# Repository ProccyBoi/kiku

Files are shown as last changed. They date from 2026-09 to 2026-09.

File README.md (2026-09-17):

# kiku

kiku is an open-source portable audio player built around an STM32H523 microcontroller. The project combines Bluetooth audio, local microSD playback, FM radio, a colour display, headphone and speaker outputs, battery management, and a custom mechanical enclosure in one hardware/firmware repository.

> **Project status:** this repository is a public engineering snapshot, not a production-approved hardware release. The firmware software gate passes on the checked-in source, but physical product qualification is still in progress. In particular, the Rev-A USB-C/power-path issue and the remaining hardware soak/validation items in [`Firmware/RELEASE_CHECKLIST.md`](Firmware/RELEASE_CHECKLIST.md) must be resolved before treating the design as production-ready. Files under `Production/` are therefore prototype/reference manufacturing outputs, not a production release.

## Features

- Bluetooth A2DP sink with AVRCP transport control and metadata through a Microchip BM83
- WAV and MP3 playback from a 4-bit SDMMC microSD card
- FM tuning, seek and RDS using the Silicon Labs SI4705-D60
- TLV320AIC3104 headphone/codec path and MAX98357A internal-speaker amplifier
- automatic headphone/speaker routing
- 2.0-inch 240 x 320 ST7789 display, rotary encoder and push-button controls
- BQ25895 charging/power-path control and MAX17048 battery state-of-charge monitoring
- FreeRTOS-based STM32H523 firmware with host tests, release/debug builds, watchdogs and diagnostics
- project-owned enclosure CAD, printable parts and mechanical packaging tools

## Hardware

The KiCad project in the repository root is the electrical hardware source of truth. The current board uses:

| Function | Device |
| --- | --- |
| Application MCU | STM32H523VET6 |
| Bluetooth audio | Microchip BM83, A2DP sink |
| Audio codec / headphones | TI TLV320AIC3104 |
| Speaker amplifier | Analog Devices MAX98357A |
| FM receiver | Silicon Labs SI4705-D60 |
| Charger / power path | TI BQ25895 |
| Fuel gauge | Analog Devices MAX17048 |
| Display | HS20HS072RX, ST7789, 240 x 320 |
| Storage | 4-bit SDMMC microSD |

The board is programmed and debugged through **SWD**. On this hardware revision, USB-C D+/D- are used by the BQ25895 input-detection circuitry and are **not routed to STM32 PA11/PA12**, so USB DFU/CDC is not available.

The historical `Walkman - Blobject.*` KiCad/manufacturing filenames are retained in this snapshot to avoid breaking project references and release tooling; the public project name is **kiku**.

## Firmware

Firmware is under [`Firmware/`](Firmware/README.md). It implements Bluetooth, local-file and FM source handling; audio routing; display and controls; battery/charger monitoring; persistent settings; watchdog/fault handling; and bring-up diagnostics.

Initialise the pinned submodules and run the host/build checks from the repository root:

```text
git submodule update --init --recursive
python Firmware/tools/test_host.py
python Firmware/tools/build.py --clean
```

For a software release candidate, run:

```text
python Firmware/tools/release_check.py --require-clean
```

The firmware build outputs `kiku.elf`, `kiku.bin`, `kiku.hex` and `kiku.map` under `Firmware/build/`. See [`Firmware/README.md`](Firmware/README.md) for the BM83 configuration contract, programming steps, controls and bring-up details.

## Mechanical design

[`Mechanical/`](Mechanical/README.md) contains the enclosure source, public STEP/STL outputs, review material and packaging scripts.

The project intentionally does **not** redistribute component 3D models whose upstream redistribution terms are unclear, nor generated populated/reference assemblies that embed those models. Public mechanical packages use project-owned geometry and recorded QA metadata. Exact component-level fit checking remains a local workflow after obtaining the required manufacturer/KiCad models under their original terms.

See [`Mechanical/REFERENCE_GEOMETRY.md`](Mechanical/REFERENCE_GEOMETRY.md) for the complete provenance and reproducibility workflow.

## Repository layout

```text
Firmware/                       STM32 firmware, tests and build/release tooling
Mechanical/                     enclosure CAD, exports, QA and packaging tools
Production/                     prototype/reference PCB manufacturing outputs
3dmodels/README.md              policy for locally obtained component models
Walkman - Blobject.kicad_*      KiCad project sources
Print.pdf                       generated PCB print output
Print Schematic.pdf             generated schematic print output
.github/workflows/firmware.yml  firmware CI
```

## Public-source scope

This repository publishes project-authored hardware, firmware and mechanical sources while deliberately excluding material that should remain with its upstream publisher. Excluded material includes third-party BM83 firmware/configuration tools and command-set documents, generated radio images, cached supplier pages, vendor datasheet copies, provenance-unclear component 3D models, and fit-check assemblies that serialise those models.

Third-party source code that is present in the tree or pulled as a submodule remains under its own upstream copyright and licence notices. The project licence does not replace those terms.

## Validation

The public snapshot is checked with:

- native firmware regression tests plus clean release/debug ARM builds;
- `Firmware/tools/release_check.py --require-clean`;
- stripped-checkout P0/P1 mechanical package builds that exclude third-party reference geometry;
- Git history, integrity, privacy and credential scans before publication.

Passing these source/software checks does not replace the physical hardware, RF, charging, mechanical, regulatory or long-duration soak tests listed in [`Firmware/RELEASE_CHECKLIST.md`](Firmware/RELEASE_CHECKLIST.md).

## Licence

kiku is a mixed-licence project:

- project-authored hardware, electronics and mechanical design material is licensed under **CERN-OHL-P-2.0**;
- project-authored firmware, tools, scripts and CI code is licensed under the **MIT License**;
- files or portions carrying their own third-party copyright/licence notices remain under those upstream terms.

The exact scope map and full licence texts are in [`LICENSE`](LICENSE) and [`LICENSES/`](LICENSES/).

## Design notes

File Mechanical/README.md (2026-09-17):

# Kiku mechanical enclosure

This folder contains the mechanical source and prototype exports for the Kiku portable audio player. The enclosure is built around the **current KiCad PCB**, not a generic board envelope.

## V8 direction

The first CAD iteration combines the earlier **Pebble clamshell** and **Lens Island** directions:

- 69 x 115 mm rounded handheld body with an 11 mm plan-view corner radius.
- 1.8 mm nominal walls for an SLS/MJF or careful FDM first prototype.
- Flush separate screen lens over the HS20HS072RX LCD.
- **Two paired pebble tactile caps** with hidden split press-fit sockets on SW3/SW4. They are rotated slightly toward each other and sit in shallow organic recesses rather than looking like generic square caps. SW1/QON remains internal.
- **Soft encoder puck** with a hidden split-collet press fit on the PEC11L 6 mm knurled shaft. A recessed M7x0.75 bushing-nut pocket is hidden underneath so the encoder can mechanically support the shell rather than loading only its solder joints.
- Real bottom USB-C and 3.5 mm jack positions from KiCad.
- Softer top microSD access: a narrower card tunnel plus a broad thumb scallop instead of a rectangular cut-out.
- Four M2 PCB standoffs at the actual board holes plus lower-edge support rails.
- Rear-to-front perimeter locating tongue with first-print slip-fit clearance.
- **Two hidden M2 case screws beneath the removable screen lens**, reusing the PCB's existing upper 2.2 mm mounting holes. Rear posts include pockets for small M2 brass inserts, so the finished exterior has no visible enclosure screws.
- **Uniform smooth rear shell** deep enough for the supplied 10 x 34 x 50 mm LiPo. The previous local battery hump has been removed.
- **No internal speaker**. LS1 remains available electrically and a 4.4 mm right-side cable egress is provided for an externally mounted speaker lead.
- **Recessed multimeter-style kickstand** on the rear. The 42 x 56 mm open-frame stand sits nearly flush when closed and uses a 1.9 mm hinge bore intended for ~1.75 mm filament or a similar smooth pin.
- **Left-side SMA bulkhead** for the external FM antenna.
- Reserved 100 mm RF1.13 U.FL-to-SMA cable route from PCB J3, down the right side and then across below the battery, deliberately leaving the BM83 lower-right RF keepout before crossing the case.
- Hinged telescopic antenna stows upward along the left side instead of lying across the rear face, with two open crescent nesting saddles to make the folded whip look intentionally parked.
- Explicit lower-right BM83/RF keepout: no battery foil, speaker magnet, metal boss or antenna-coax bundle should be added there.

V8 deliberately prioritises appearance over absolute minimum thickness. The body remains a uniform **28.7 mm nominal thickness**, absorbing the 10 mm battery without a rear hump and keeping the front speaker-free. Fasteners are hidden beneath the screen lens, the microSD opening is softened into the top edge, and the folded FM whip gains intentional nesting features rather than hanging loose from the SMA hinge.

## Source of truth

`reference/board_datums.json` is generated from `Walkman - Blobject.kicad_pcb` by `scripts/extract_board.py`. Its mechanical coordinate system is:

- X = PCB X - 72.11 mm
- Y = 157.90 mm - PCB Y
- Z = 0 at PCB rear, +1.6 mm at PCB front

Do not hand-edit the KiCad-derived datums. Re-run the extractor after board changes, then rebuild and review the enclosure.

## Build

Project-owned enclosure/part source and exports are redistributable. The strict
hardware fit-check additionally requires the component 3D models referenced by
the KiCad board; those inputs are intentionally not bundled. See
`REFERENCE_GEOMETRY.md` before rerunning a full hardware-reference validation.

From the repository root, after preparing those local references when a full
fit-check is required:

```powershell
python Mechanical/scripts/build_housing.py
```

CadQuery 2.8 or newer is required.

## Exported parts

`exports/` contains project-owned STEP and STL for:

- front shell
- rear shell
- rear kickstand
- screen lens
- left/right button caps
- encoder knob
- housing-only assembly STEP
- individual printable/manufactured parts
- packaging/keepout STEP

The populated PCB fit-check STEP is a local generated artefact because it embeds
third-party component-model geometry. It is intentionally not redistributed.
The public tree retains `reference/pcb_bare.step`, board datums, component
reference metadata, project-owned housing geometry and recorded QA results.

`review/` also contains validation data and front/rear/exploded PNGs generated by:

```powershell
python Mechanical/scripts/render_review.py
```

Third-party datasheet copies, supplier-page captures and component-library 3D
models used during development are intentionally not redistributed by the public
source tree unless their licence is explicitly recorded. The reports retain the
source links and measured requirements needed to reproduce the design review;
project-derived PCB/enclosure geometry remains checked in.

P0/P1 frozen `REF_*.brep` files and populated fit-check assemblies are likewise
local-only. They can be regenerated after obtaining the exact model inputs under
their original terms; the public packaging scripts never copy them into a
redistributable package.

## Parameters that are intentionally not production-frozen

- LiPo pack: V8 uses the supplied **10 x 34 x 50 mm** envelope. The stated capacity is 200 mAh; dimensions are treated as the mechanical source of truth. Final cable exit, protection-PCB position and swelling allowance still need physical verification.
- Speaker: V8 intentionally has **no internal speaker cavity, grille or speaker bulge**. The LS1 PicoBlade output remains on the PCB and exits through the right-side cable passage for an externally mounted speaker.
- Kickstand: V8 uses a recessed open-frame stand with a nominal **62 degree open reference angle**. The first prototype uses hinge friction rather than a moulded detent; tune or drill the 1.9 mm bore for the chosen print process/pin if needed.
- LCD: body and active-area dimensions follow the current HS20HS072RX drawing, but final adhesive/foam stack and FPC bend need a physical fit check.
- FM: the ordered pigtail is an RF1.13 U.FL/IPX-to-SMA bulkhead lead; the 100 mm option is reserved. The ordered telescopic antenna listing shows **105 mm collapsed, 310 mm extended and 9 mm diameter** with a hinge. V8 mounts the SMA on the left side at Y=18 mm, reserves an 88.3 mm internal route plus service slack, and adds open nesting saddles at Y=48 and 84 mm.
- Controls: SW3/SW4 use a measured/modelled 7.2 mm square actuator. V8 caps use a nominal 7.05 mm four-way split socket with a larger lead-in, giving a deliberately small compliant press fit instead of a loose post. The encoder uses a 5.75 mm split-collet bore on the 6.0 mm 18-tooth knurled shaft. PA12 is preferred for these compliant details; FDM users should tune the press fits from the first test print if required.
- Fastening: use two low-profile/button-head M2 screws with **head height <= 1.3 mm** through the upper PCB mounting holes, into the rear post insert pockets. Tighten these before fitting the screen lens; the lens then conceals both screw heads.
- Positive snap retention / cosmetic parting-line refinement / heat-set insert details are deliberately deferred until V1 dimensional fit is verified; V1 includes a locating tongue but is intended to be taped/clamped for the first dimensional fit if required.

## First prototype review

Before treating this as production CAD, verify:

1. PCB drops onto all four posts without stress and the lower cradle does not contact solder joints.
2. USB-C and headphone plugs fully seat through the case openings.
3. microSD can be inserted and removed comfortably through the top thumb scallop with the LCD installed.
4. Both pebble caps press securely onto SW3/SW4, remain removable with deliberate pulling force, and do not preload the switches.
5. Button caps move through the tactile travel without rubbing the front-shell recesses.
6. Encoder split collet grips the 6.0 mm knurled shaft securely; optional M7x0.75 nut/washer clears beneath it and push-to-select still has full travel.
7. Battery does not touch the PCB, mounting screws, coax route or rear-wall features.
8. External speaker lead passes freely through the 4.4 mm right-side egress.
9. Kickstand closes into its recess, rotates freely, and provides useful friction with the selected hinge pin.
10. Hidden M2 screws clamp the shell/PCB stack correctly, their heads stay below the lens underside, and the lens can still be removed for service.
11. SMA bulkhead/nut fits the 6.8 mm left-side hole, U.FL/coax reaches without entering the BM83 keepout, and the hinged antenna rests cleanly in both side saddles without fouling the case.

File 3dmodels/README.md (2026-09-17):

# Component 3D models

The public source tree intentionally does not redistribute the local component
3D-model bundle. Several models originate from manufacturer/library/EasyEDA
sources and the project does not have a single documented redistribution licence
covering the complete bundle.

The KiCad schematic and PCB remain the electrical source of truth and do not
require these optional models for fabrication or firmware builds. For local 3D
review, obtain the applicable models from the original manufacturer, KiCad
library or component-library source under its own licence and place them in this
directory using the filenames referenced by the board. Local model files are
ignored by Git. `Mechanical/REFERENCE_GEOMETRY.md` documents the exact local
reference workflow and the source audit command.

Project-generated enclosure, bare-PCB and manufacturing geometry remains under
`Mechanical/` and `Production/` where it is part of the kiku source tree. A
populated PCB STEP, frozen transformed component BREPs and fit-check assemblies
that embed those third-party models are intentionally local-only outputs.

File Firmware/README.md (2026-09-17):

# kiku firmware

Production-oriented firmware for the STM32H523VET6 board in the repository root. The KiCad schematic/PCB is the hardware source of truth; the firmware pin map is deliberately kept in `Core/Inc/board.h` and `Core/Src/board.c` rather than a generic development-board definition.

## Implemented product functions

- BM83 Bluetooth A2DP receive path over I2S2, Host MCU UART framing/ACK, MFB wake timing, AVRCP play/pause/next/previous and AVRCP 1.3 title/artist/album metadata requests.
- microSD library scan over 4-bit SDMMC1 with UTF-8 long filenames, hot-insert remount/rescan, PCM WAV playback and MP3 playback through minimp3. A missing card is non-fatal.
- SI4705 FM power-up, tune, seek, signal-quality polling and RDS Program Service/RadioText decoding. FM analogue L/R is routed into the TLV320AIC3104 ADC and looped through the I2S1 DAC/speaker path so both headphones and the internal speaker receive the selected station.
- TLV320AIC3104 I2S/headphone routing plus MAX98357A speaker control with selectable AUTO, headphones, speaker and both-output modes. AUTO uses the speaker when the jack is empty and headphones when a plug is inserted.
- BQ25895 charger status and MAX17048 battery state-of-charge monitoring. Rev A is forced to a 5-V-only, 500-mA input profile at the very start of platform initialisation: automatic D+/D- detection, HVDCP and MaxCharge negotiation are disabled before slow peripheral work. Charge-current programming remains disabled by default because the final cell/enclosure/thermistor limits cannot be derived from the PCB.
- ST7789 320x240 status/now-playing UI, PWM backlight, rotary encoder and three push controls.
- CRC-protected persistent settings (`KIKU.CFG` on microSD, with read-only migration from the older development filename), watchdog, non-destructive peripheral self-test API and recoverable optional-peripheral failures.
- FreeRTOS on Cortex-M33, HAL timebase isolated on TIM6, DMA-capable peripheral setup and exact STM32H523 startup/linker configuration.

## Controls

| Control | Local audio | FM | Bluetooth |
| --- | --- | --- | --- |
| Encoder | Volume | Volume by default; fine tune when toggled | Volume |
| Encoder press | Open SD/library menu | Toggle FM knob between volume/tune | Return to sources |
| Encoder long press | Return to sources | Return to sources | Return to sources |
| Button 1 | Play/pause | Previous preset | Play/pause |
| Button 1 long press | Switch to local | Seek down | Pair if disconnected; otherwise local |
| Button 2 | Next/random track | Next preset | Next track |
| Button 2 long press | Switch to FM | Seek up | Switch to FM |

Shuffle is owned by the SD/library menu rather than global Settings. It changes
local next-track selection only and is persisted with the other user settings.

When Bluetooth is selected, firmware automatically reconnects the last paired
A2DP device with bounded backoff. Normal BM83 UART traffic does not pulse MFB;
BM83 does not expose the `UART_RX_IND` function used by earlier BM62/BM64 parts.
If no device reconnects, the Bluetooth screen shows `HOLD B1 TO PAIR`; holding
Button 1 enters BM83 pairing mode without clearing existing pairing records.

## Required BM83 configuration

The PCB gives the BM83 its own digital-audio clock path but does not route BM83 MCLK to the STM32. This firmware therefore expects the BM83 configuration image to use:

- Host MCU mode enabled;
- UART at 115200 baud;
- A2DP sink and AVRCP enabled;
- I2S audio output at 48 kHz, 24-bit stereo;
- BM83 acting as the I2S BCLK/LRCLK host (STM32 I2S2 is configured as slave receive).

The connected development BM83 has now been measured as MSPK2 firmware v1.2.
That image is suitable for bench compatibility testing but is **not** the kiku
production radio baseline: Microchip's MSPK2 v1.3 release notes explicitly fix
the defect where firmware stops responding to UART `0x4A` after many requests.
Use an SPP Host-Mode MSPK2 v1.3-or-newer compatible image for a golden unit,
then archive its exact firmware/configuration hashes with manufacturing records.
Vendor tools, documentation and generated BM83 images are intentionally not
redistributed by this public repository; see [`BM83_tools/README.md`](BM83_tools/README.md).

If OTA DFU is not a deliberate product feature, disable it in the BM83
configuration. If it is shipped, replace all example/default credentials with a
production secret provisioned outside source control.

## Build and test

Dependencies are checked in or pinned as Git submodules. On Windows the build script automatically finds the GNU Arm toolchain installed by PlatformIO; elsewhere `arm-none-eabi-gcc`, `objcopy` and `size` can be on `PATH` or supplied through `ARM_GCC_PREFIX`.

```text
git submodule update --init --recursive
python Firmware/tools/test_host.py
python Firmware/tools/build.py --clean
```

Outputs are written to `Firmware/build/`:

- `kiku.elf`
- `kiku.bin`
- `kiku.hex`
- `kiku.map`

The same host tests plus clean release and debug cross-builds run in GitHub Actions. The workflow rebuilds release mode last so its uploaded artifacts are the production binaries.

For a release candidate, run `python Firmware/tools/release_check.py --require-clean`.
The build also emits `kiku-build-manifest.json` containing SHA-256 hashes, the
compiler identity and Git revision. The complete software/hardware sign-off is
in [`RELEASE_CHECKLIST.md`](RELEASE_CHECKLIST.md); a passing build alone does
not waive unresolved hardware validation.

## Programming

This board is programmed through the 10-pin ARM SWD connector. The USB-C D+/D- lines terminate at the BQ25895 charging circuitry; STM32 PA11/PA12 are not connected on this hardware revision, so USB DFU/CDC/MSC is not available.

With an ST-Link and STM32CubeProgrammer, a typical command after building is:

```text
STM32_Programmer_CLI -c port=SWD -w Firmware/build/kiku.hex -v -rst
```

## Audio architecture

The MCU/codec audio domain is fixed at 48 kHz. Local files from 8-96 kHz are converted to 48 kHz by a deterministic nearest-neighbour resampler before I2S output. Bluetooth PCM arrives from BM83 on I2S2. SI4705 FM analogue audio enters TLV320AIC3104 LINE2; the codec ADC return is forwarded through I2S1 to the codec DAC and MAX98357A path. AUTO output disables the speaker amplifier whenever headphones are inserted; explicit Speaker and Both modes override that automatic policy. Software volume scaling is applied before I2S transmission.

The simple resampler is intentional for first hardware bring-up and correctness. A band-limited asynchronous resampler is the appropriate later upgrade if listening tests show the BM83 and codec clock domains need drift compensation or higher-quality sample-rate conversion.

## First hardware bring-up checks

The repository is fully build/test checked without attached hardware. These physical facts still require measurement on the assembled product and are kept isolated so they do not contaminate the protocol/board implementation:

1. Program and record a golden BM83 using a compatible MSPK2 v1.3-or-newer SPP
   Host-Mode image, confirm the interface requirements above, and verify
   long-duration clock-domain and metadata behaviour. The STM32 host is hardened
   against the v1.2 repeated-`0x4A` defect, but that does not make v1.2 an
   acceptable production radio baseline.
2. Confirm `HP_DET` polarity with the actual SJ1-3525N jack; change the single active-level argument in `Platform/Src/platform.c` if required.
3. Confirm ST7789 rotation, RGB/BGR order and inversion for the exact HS20HS072RX panel; adjust the startup sequence/offset constants only if the physical panel requires it.
4. Set BQ25895 charge current/input-current/thermal policy only after the exact LiPo cell rating, NTC network and enclosure thermal performance are known. `APP_BENCH_CHARGE_POLICY_ENABLE` remains `0` by default.
5. Rev A uses F1 = C883127 (6-V, 750-mA PTC) and a 5-V-class TVS on VBUS. The BQ25895 reset defaults permit D+/D- high-voltage-adapter negotiation, so firmware explicitly disables AUTO_DPDM/HVDCP/MaxCharge and fixes IINLIM at 500 mA before SD/Bluetooth/display initialisation. This greatly reduces risk when the MCU is running, but a future PCB revision should make the 5-V-only requirement true in hardware as well rather than relying solely on post-reset I2C configuration.

## Source layout

```text
Firmware/
  Core/        STM32H523 clocks, pins, HAL MSP/IRQs, FreeRTOS config
  Drivers/     BM83, BQ25895, MAX17048, SI4705, ST7789, TLV320AIC3104, audio I/O
  Audio/       minimp3 adapter
  Storage/     FatFs/SDMMC storage and settings adapters
  App/         product state, playback, input, radio, power, settings, self-test
  Platform/    HAL-to-driver integration and audio routing
  UI/          display renderer
  tests/       native protocol/state unit tests
  tools/       reproducible build/test scripts
```

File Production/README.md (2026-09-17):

# Production outputs

This directory contains Gerber and drill outputs generated from the current kiku PCB design. They are retained as **prototype/reference manufacturing outputs** for reproducibility and review.

They are **not a production-approved fabrication release**. The current Rev-A hardware still has unresolved power/USB-C and physical qualification items documented in [`../Firmware/RELEASE_CHECKLIST.md`](../Firmware/RELEASE_CHECKLIST.md). Resolve and sign off those blockers on the intended PCB/BOM revision before ordering production hardware from these files.

The historical `Walkman - Blobject` filenames are retained to match the KiCad project and existing generated-output workflow.

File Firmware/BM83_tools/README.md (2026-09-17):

# BM83 production package

This directory intentionally does **not** redistribute Microchip BM83/IS2083
firmware, configuration tools, command-set documents or generated radio images.
Obtain the applicable BM83 software package and documentation directly from
Microchip, then archive the exact production inputs and hashes with the build
and manufacturing records rather than in the public source repository.

## kiku radio requirements

The production BM83 configuration must provide:

- MSPK2 SPP firmware v1.3 or newer compatible firmware. The connected v1.2
  development module reproduced Microchip's documented defect where repeated
  UART `0x4A` AVRCP vendor-dependent requests eventually stop receiving a
  response; the BM83 MSPK2 v1.3 release notes list this defect as fixed.
- Host MCU mode at 115200 baud.
- A2DP sink and AVRCP enabled.
- 48 kHz, 24-bit stereo I2S output with the BM83 providing BCLK/LRCLK to the
  STM32 I2S2 slave receiver.
- A production-specific Bluetooth device name and profile configuration.
- OTA DFU disabled when it is not a product requirement. If OTA DFU is shipped,
  provision a non-default production secret outside Git and include it in the
  manufacturing security process; never ship the Config Tool example/default
  key.

The STM32 firmware deliberately keeps the field-proven `0x4A` metadata path and
also serialises title, artist and album into separate physical requests. The
three fields are staged and committed atomically. An accepted request whose
`0x5D` response is missing remains owned instead of being blindly retried, so a
faulty/older BM83 cannot be driven into a UART resource-exhaustion loop.

## Golden-unit record

For every production release, record at minimum:

- BM83 8051 firmware variant and version;
- DSP firmware version;
- UART command-set / Host MCU version reported by the module;
- configuration image SHA-256;
- radio firmware image SHA-256;
- production device-name/profile configuration;
- whether OTA DFU is disabled or the identifier of the external secret record;
- a sustained metadata-soak result on the exact programmed radio image.

Do not treat files left in this directory on a development workstation as
release artefacts unless they match the signed golden-unit record.

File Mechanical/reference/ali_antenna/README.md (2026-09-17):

# FM antenna mechanical reference

Source products supplied by the project owner:

- Telescopic antenna: `https://www.aliexpress.com/item/1005007806214529.html`
- U.FL/IPX to SMA RF1.13 pigtail: `https://www.aliexpress.com/item/1005009812335103.html`

## Telescopic antenna

The listing title identifies a hinged SMA rod/telescopic antenna intended for 40 MHz to 6 GHz. Supplier dimensions recorded during the mechanical review are:

- collapsed overall length: **105 mm**
- extended overall length: **310 mm**
- maximum body/base diameter shown: **9 mm**
- 90-degree hinge at the connector end

The listing artwork is internally inconsistent about the connector naming (title says SMA while one image labels an F-type connector), so V2 does **not** assume antenna gender in the printed geometry. It provides clearance around a conventional 6.35 mm SMA bulkhead thread and leaves the removable antenna outside the print.

Cached supplier HTML and product images are deliberately excluded from the
public source tree. Use the source-product links above for the current listing;
local cached copies, when present on an engineering workstation, are ignored by
Git.

## Pigtail

The second listing is an RF1.13 coax pigtail family with U.FL/IPX at the PCB end and SMA/RP-SMA bulkhead variants. The exact ordered lead is treated mechanically as:

- nominal cable length: **100 mm**
- cable type: **RF1.13**
- PCB end: U.FL/IPX for Kiku J3
- enclosure end: SMA-style bulkhead

V2 uses a **6.8 mm bulkhead hole** and a **12 mm-diameter local reinforcement boss**. The larger boss is deliberate: if the delivered telescopic antenna/pigtail combination turns out to need a larger bulkhead despite the listing's SMA wording, the prototype hole can be cautiously opened up without reprinting the shell. The internal reserved cable centreline is approximately **88.3 mm**, allowing connector transitions and a small amount of service slack without coiling the cable tightly.

## Housing routing decision

J3 is at mechanical XY `(57.395, 66.55)` mm, very close to the right PCB edge. The cable first goes down the right side, then crosses towards the left only below the battery. The diagonal crossing leaves the lower-right BM83 RF keepout before it moves left. The bulkhead is at the left side around Y=18 mm. This also lets the hinged telescopic rod fold upward along the left side, keeping the 9 mm antenna body off the rear face and preserving the thinnest practical body profile.

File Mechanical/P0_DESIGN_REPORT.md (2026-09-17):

# Kiku / Mame P0 mechanical design

**Engineering development release. Not approved for production tooling.**

This version is generated by `scripts/housing.py` and `parameters.json`. Its outputs are isolated in `exports/P0/`. Other `kiku_*_v1` files in the parent export folder belong to a separate design iteration and are not interchangeable with these parts.

## Hardware basis and coordinate system

The current `Walkman - Blobject.kicad_pcb` is the dimensional authority. `reference/board_datums.json` records its SHA-256, every footprint position, mounting pad/drill, model transform, and board outline. The PCB file is not modified. The exact board outline, including the jack notch and asymmetric bottom-left corner, is retained in the reference STEP.

Mechanical X = KiCad X - 72.11; mechanical Y = 157.90 - KiCad Y; Z = 0 at the nominal board back, positive toward the controls. The nominal board is 60 x 105 x 1.6 mm. The KiCad bare-body STEP omits some conductor thickness; compare its reported Z extent with the nominal 1.6 mm stack before using imported surfaces as mounting datums.

| Interface | Mechanical centre X, Y (mm) | Evidence |
|---|---:|---|
| Left key SW3 | 16.000, 55.000 | KiCad footprint and supplied STEP |
| Right key SW4 | 44.000, 55.000 | KiCad footprint and supplied STEP |
| Encoder SW2 | 30.000, 40.000 | KiCad footprint; PEC11L drawing for Z |
| QON power/wake SW1 | 24.950, 20.910 | KiCad footprint and /QON net |
| USB-C J1 | 20.090, mating face Y = -0.100 | STEP mating face, axis Z = 3.250 |
| Headphone J6 | 7.570, axis parallel to Y | STEP bore, axis Z = 4.100 |
| microSD J2 | 36.965, 96.350 footprint datum | Hirose STEP; opening follows mouth |
| PCB H5/H6 | 6.000 / 54.000, 99.000 | Actual 2.2 mm drilled mounting pads |
| PCB H7/H8 | 6.000 / 54.000, 37.000 | Actual 2.2 mm drilled mounting pads |

The component inventory differentiates supplied STEP solids, envelopes extracted from VRML vertices, and the missing D3 model. VRML envelopes are conservative bounding boxes, not replacement manufacturer CAD. The encoder's attached PEC11R-labelled model reaches only about Z = 21.1 mm. Its specified PEC11L-4120F-S0020 drawing instead puts the nominal shaft tip at Z = 26.1 mm. P0 uses the specified part's dimensions and retains the discrepancy as an incoming inspection item.

## Three concepts and selection

See `concepts/three_concepts.png`, individual front/rear/profile/perspective images, and the three concept STEP files. These are exterior studies sharing the board, display, and control datums; they do not represent three independently finished mechanisms.

| Concept | Assembly approach | Advantages | Disadvantages |
|---|---|---|---|
| **Mame: soft pebble** | Two shells, internal lens carrier, rear screws | Balanced width around a fixed rectangular PCB; broad rear grip; gentle lower-left swell gives identity with screen off; suitable room for isolated cell and speaker | Fuller than the board; long encoder creates local depth; organic surface requires careful finishing |
| **Nagare: offset swell** | Same two-shell stack, larger asymmetric right-hand grip | Most expressive silhouette; thumb-side volume is comfortable for a right-handed grip | Extra width with no hardware benefit; less neutral in the left hand; greater pocket bulk |
| **Mini: restrained capsule** | Two shells with smaller perimeter allowance | Smallest outline; most familiar MiniDisc-era proportions; least plastic | Less room around side bosses and lead dress; flatter identity; tight margins make tolerances harder |

Engineering judgement scores, 1 = weak and 5 = strong; equal weighting:

| Concept | Identity | Ergonomics | Manufacture | Assembly | Robustness | Fixed hardware | Total / 30 |
|---|---:|---:|---:|---:|---:|---:|---:|
| Mame | 4 | 4 | 4 | 4 | 4 | 5 | **25** |
| Nagare | 5 | 3 | 3 | 4 | 4 | 4 | 23 |
| Mini | 3 | 4 | 4 | 3 | 3 | 4 | 21 |

Mame is selected. Scores describe design judgement, not user testing. The front is warm opaque ivory, rear satin muted green, primary key orange, other controls tonal green/ivory, and the window smoked with an opaque reverse mask. The lower front has room for a small printed Kiku wordmark; the rear upper flat has a 26 x 12 mm reserved product-information area. No false vents or decorative grooves are used.

## Stack and construction

**Approximate overall envelope: 77.1 mm wide x 120.9 mm tall x 46.8 mm deep including the knob**, from exported mesh extrema at 0.08 mm tessellation tolerance. The main shell extends from Z = -18.0 to +15.2 mm: **33.2 mm nominal body depth**. Raised keys and encoder add local depth; the knob top is Z = 28.8, so the total nominal front-to-back envelope is **46.8 mm**. This is a material ergonomics limitation of the specified 20 mm encoder shaft and the 10 mm thick battery. The interface review supplies the exported mesh extrema for approximate manufacturing envelope dimensions; the BREP inventory also records bounding boxes, which can overbound curved spline surfaces. Do not substitute a shorter shaft or thinner battery without an explicit hardware decision.

Housing skins use 1.8 mm nominal walls. Plan offsets follow sampled inward curve normals; the front/rear edge rolls approximate 3.5/4.0 mm quarter-rounds with 15-degree CAD segments. This is an explicit prototype construction, not a Class-A mould surface. Surface continuity, local wall mapping and minimum neck sections must be rebuilt/verified for tooling. Internal bridge ribs are 1.4 mm wide and locally 1.0 mm deep. Boss roots require physical torque/drop testing.

### Display and lens

The user permits a floating display above the PCB. Its body is 51.8 x 36.2 x 2.05 mm, with a 40.8 x 30.6 mm active area, from the [HS manufacturer drawing](https://atta.szlcsc.com/upload/public/pdf/source/20251016/BAE15D01F6ECB51EA8350D6C5C8F6372.pdf), sheet 10. The KiCad placement rectangle is 0.01 mm shorter in Y; P0 preserves its centre and uses the drawing's actual body size.

P0 orients the tail toward the PCB's right-side FPC connector. The active area is offset 2.66 mm left of the module centre in this orientation; the aperture follows it rather than centring it blindly in the body. The 41.6 x 31.4 mm aperture provides 0.4 mm nominal overscan per edge. The 54 x 37.8 x 1.0 mm lens is recessed 0.2 mm, with 0.3 mm perimeter clearance and a 0.2 mm adhesive seat. Mask the lens reverse face around the optical aperture. The LCD top is at Z = 12.50, with 0.40 mm nominal clearance to the bezel underside. The removable carrier supports the backlight frame through a thin compliant strip; it does not clamp the active glass.

The FPC route is a reserved folding space, not a proven cable model. Confirm the supplied tail orientation, contact side, usable length, bend radius and latch access with the actual panel before fastening the carrier. Do not sharply crease the FPC.

### Controls

Both large caps have captured flanges and a 0.35 mm nominal radial guide allowance at the exposed cap. A small underside contact feature meets the switch actuator. The actual switch operating stroke, force, and tolerance were not supplied. The housing is checked at 0, 0.5 and 1.0 mm downward cap displacement; this tests housing space, not the switch itself. Verify take-up, overtravel stop and return before powered use. Add a compliant return/anti-rattle element only after measuring the force budget.

SW1/QON remains an internal service control in this iteration; no external plunger is supplied. Confirm the intended user power/wake behaviour in firmware before accepting this interface. The encoder uses a 21 mm outside diameter knob, a 6.24 mm D-shaped nominal socket, an integrated housing guide around its skirt, and a radial M2 grub screw in a metal insert. The [Bourns PEC11L drawing](https://www.bourns.com/docs/product-datasheets/pec11l.pdf) specifies 0.5 mm nominal switch travel with +0.4/-0.3 mm tolerance; P0 reserves 1.2 mm between the knob shoulder and raised island before push. The skirt counterbore extends above the full-round shaft section; the D socket starts where the flat is available. Housing clearance is checked at 0, 0.45 and 0.9 mm downward knob displacement. Check the installed shaft length and knob axial setting over the whole 0.2-0.9 mm switch stroke.

### Battery

The user-specified cell envelope is **34 x 50 x 10 mm**, reported capacity 200 mAh. Capacity is not inferred from its physical size. Its nominal location is X = 13..47, Y = 45..95, Z = -15.2..-5.2. Foam supports the pouch; side rails provide 0.5 mm nominal lateral clearance. A removable insulating guard at Z = -3.8 leaves **1.4 mm nominal space above the pouch**, with no intentional compression from shell screws. Supplier dimensional tolerance, protection board, lead exit, and swelling requirements remain unverified. That 1.4 mm is a packaging reserve, not a claim that a damaged/swollen cell is safe to keep using.

The guard and its fasteners remain outside the nominal cell footprint. Radius/finish every pouch-facing edge. Use a pull ribbon under the battery and disconnect it before service; do not permanently bond the cell into the case. Confirm the connector's cable bend and unplugging space. A printed guard is a prototype; a smooth insulating sheet is preferable once its shape is validated.

### Speaker

Selected part: **XHXDZ 20MM-8ohm2W-JFHM, LCSC C50387209**. Its [manufacturer drawing hosted by LCSC](https://datasheet.lcsc.com/datasheet/pdf/8e0aa0a2b86c456182d861902de24ed3.pdf?productCode=C50387209) gives 20 +/- 0.2 mm diameter and 5.1 +/- 0.3 mm total depth. The alternative [C50387215](https://www.lcsc.com/product-detail/C50387215.html) is 30 mm; it is not interchangeable with this retainer.

The selected driver fires toward seven rounded rear slots. A soft rim gasket spaces the diaphragm from the grille. A separate screwed cover and compliant rear perimeter support retain the driver. The pocket is 21.0 mm diameter, giving 0.5 mm nominal radial clearance and 0.4 mm with the maximum listed diameter. A small rear cavity and a sealed wire notch avoid a direct uncontrolled front-to-back air path. The pull-tab outline is not fully dimensioned by the manufacturer; its relief is provisional. Seal the relief with compliant material, then check cone travel, rattles and acoustic leakage. The cavity has not been acoustically tuned or measured; no SPL/bass claim is made.

### Ports and antennas

The USB-C passage is a 13 x 7 mm overmould gauge following the actual mating axis; the headphone passage accepts an 11 mm cylindrical overmould on the real jack axis. These are explicit test gauges, not a guarantee for every cable. Entrance edges require a small deburr/chamfer after printing. Check full seating with a straight plug, a bulky plug, and multiple USB-C cables. The opening supports a contacting cable overmould laterally, but connector solder joints still carry loads until contact; no separate connector strain-relief rating is claimed.

The microSD tunnel and enlarged top finger relief extend back toward the socket so a thumbnail can reach the card. Verify the actual push-push latch, card lock/eject positions and fingertip access with the lens/carrier installed. The insertion corridor intentionally overlaps the reference connector where the card mates; it must clear the plastic housing.

No metallic decoration is used. Keep the lower-right BM83 antenna region free of new metal. [Microchip's module integration guidance](https://onlinedocs.microchip.com/oxy/GUID-414904F5-364E-4377-B959-9226AD29D6A9-en-US-7/GUID-495EA464-310A-41EC-A892-5E46727B10FC.html) calls for at least 15 mm between the PCB trace antenna and external metal for best range. The supplied BM83 STEP places the antenna trace solids at X = 55.34..58.74, Y = 4.78..16.78, Z = 2.2..2.3 mm. A conservative bounding-box audit against added metal gives a minimum separation of 18.32 mm (PCB screw H8), 30.34 mm to the battery envelope and 29.82 mm to the speaker envelope. The interface review records each checked item. This geometric separation is not RF validation. The FM coax guide runs under the PCB on the right. The U.FL transition and final radiating antenna are provisional; the coax alone is not treated as an FM antenna.

## Fasteners and service sequence

Nominal designed interface allowances (not a measured whole-assembly minimum):

| Interface | Allowance | Qualification |
|---|---:|---|
| Large key stem / guide | 0.35 mm per side | Fit coupon; switch return and process texture |
| Encoder skirt / guide | 0.30 mm radial | Rotation and push under side load |
| Lens perimeter / pocket | 0.30 mm per side | Lens cutting tolerance and adhesive thickness |
| LCD face / bezel underside | 0.40 mm | Installed module and carrier tolerance |
| Speaker diameter / pocket | 0.50 mm radial nominal; 0.40 mm at max listed driver diameter | Pocket process tolerance still additional |
| Battery / side rails | 0.50 mm per side | Pouch, protection board and lead tolerances unknown |
| Battery top / insulating guard | 1.40 mm nominal | Verify real cell and supplier expansion guidance |
| FM coax / guide groove | 0.30 mm radial | Provisional 1.4 mm cable diameter |
| M2 screw / nominal clearance hole | 0.10 mm radial | Finish 2.2 mm holes to fit; do not force screws |
| Seam locating tabs / pockets | 0.30 mm per side | Check seam fit after print cleanup |

One screw diameter, M2, is used throughout: four M2 x 18 case screws, four M2 x 6 PCB screws, ten M2 x 4 carrier/guard/speaker screws, and one M2 x 6 grub screw. Nineteen insert envelopes are modelled at 3.2 mm OD x 4.0 mm length; this is a design envelope, not a verified supplier part number. Select a matching insert and qualify its installation bore/process before printing the whole housing. CAD fasteners are plain shank/head/thread-envelope representations, not helical threads. PCB screws are 6 mm long, small carrier/guard/speaker screws 4 mm, rear enclosure screws 18 mm, and the knob uses a 6 mm grub screw. Confirm lengths against the final purchased head geometry, insert specification and blind-hole depth. Do not tighten a screw that bottoms in a blind hole. PCB mounts land on the existing grounded mounting pads; visually inspect surrounding copper before torque testing.

1. Install and inspect threaded inserts in the printed shells and knob.
2. Fit the lens with its removable perimeter adhesive/mask and install the LCD/carrier with compliant frame supports.
3. Place the two large caps in the front guides with the front face supported on a soft assembly nest.
4. Connect/fold the FPC, then place the PCB on the four real mounting datums and install its screws. Verify every button's return.
5. Fit the encoder knob at the checked axial setting and tighten the radial grub screw.
6. Install the rear speaker gasket, driver, rear compliant ring, and screwed cover; dress and seal its leads.
7. Fit the foam and battery in the rear pocket; install its removable guard and dress the FM coax.
8. Connect battery and speaker while the shells are open beside each other. Fold leads into the reserved space, close the shells and tighten the four rear screws in stages.
9. Check power, both keys, encoder rotation/push, USB plug seating, headphones, microSD ejection and speaker buzz before normal use.

The battery and PCB are serviceable by screws. Only the display lens uses adhesive. A practical assembly nest and temporary tape may be useful during a first build; permanent tape must not substitute for missing retention.

## Manufacturing and validation limits

Preferred first builds: SLS PA12 or tough SLA resin for geometry evaluation; carefully oriented PETG/ABS/ASA FDM for fit development. Do not rely on heat-set inserts in brittle standard SLA resin. Use process-compatible press/bonded inserts for resin, with the bore requalified. FDM shell faces need support under curved skins; remove support carefully at lens edges and guides. Print a clearance/insert coupon before a complete enclosure. STL units are mm; parts are exported in assembly coordinates and should be laid onto appropriate print faces in the slicer.

For an FDM first article, orient the rear with its outside back toward the bed and cavity upward; support the initial curved perimeter where the slicer requires it. Orient the front with its cosmetic face toward a supported build surface and its open interior upward; protect the window seat during support removal. Put the knob's closed top toward the bed so its shaft socket opens upward. Print carrier, guard and speaker retainer flat; keep supports out of insert bores. Orient key caps to support the flange and small underside contact feature. These are starting orientations requiring slicer review, not support-free printing claims. Prefer SLS for the first complete cosmetic fit build.

Before injection moulding: replace faceted meridian rolls with smooth drafted surfaces; perform a real wall-thickness/draft/undercut audit; reduce boss sink risk with cored/ribbed roots; add material-specific shrink; split/slide-tool the lateral connector openings and guide details; resolve ejection, gates, cosmetic parting line and texture. P0 is not mould-ready tooling geometry.

The machine-readable `review/clearance_review.json` is the source for the actual checks performed. `review/interface_review_P0.json` additionally records nine discrete control positions with zero shell overlap, six potentially adjacent fastener/reference pairs with zero overlap (other pairs are separated by bounding boxes), the conservative antenna separation audit, and external mesh dimensions. It distinguishes surface screening from exact collision volumes. It must not be represented as complete tolerance validation. Remaining physical gates include real component/model agreement, all cap strokes, cable/plug/card access, FPC/coax dressing, insertion/torque/pull-out, drop strength, battery lead/swelling reserve, acoustic leakage/buzz, RF range, charging heat, and pocket/one-hand ergonomics.

## Verification result

The nominal check set covers both shells, the display carrier and lens, battery guard, speaker retainer, both caps, the encoder knob, PCB/components and separate hardware envelopes. Explicit gauges cover USB-C (13 x 7 mm), headphone overmould (11 mm diameter), microSD insertion/finger access and the provisional FPC folding space. Control end positions and metal/antenna separation are in the supplementary interface review. All eight current prototype STL meshes are closed with consistent winding and one connected body. Results apply to this P0 inventory; they do not establish continuous-motion clearance, local wall thickness, complete containment or a tolerance-certified assembly.

## Editable source and deliverables

`parameters.json` and `scripts/housing.py` are the native editable CadQuery source. This is a feature-generating program, not a FreeCAD/Fusion feature tree. References remain separate named assembly components. STEP and individual prototype STL exports are in `exports/P0/`; concept STEP/views are in `concepts/`; assembled, exploded, interior and section images are in `review/P0_*`. Rebuild with the isolated environment:

The public package excludes transformed component-reference BREPs, the populated
PCB STEP and fit-check assembly STEP because those files serialise third-party
component models. `REFERENCE_GEOMETRY.md` documents how to obtain the exact local
inputs under their original terms before repeating the full strict reference QA.
The checked-in JSON reports retain the reviewed results without redistributing
those model solids.

```powershell
& Mechanical/.venv/Scripts/python.exe Mechanical/scripts/housing.py
& Mechanical/.venv/Scripts/python.exe Mechanical/scripts/verify.py
& Mechanical/.venv/Scripts/python.exe Mechanical/scripts/render_p0.py
```

After a board change, first rerun `extract_board.py` with KiCad's Python and refresh both reference STEP exports. Recheck all dependent geometry before printing.

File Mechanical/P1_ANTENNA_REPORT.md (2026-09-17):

# Kiku / Mame P1 — FM antenna integration

P1 corrects the antenna omission in the delivered Mame P0 housing. It adds the external fitting, folding space and a complete internal route for the user's **100 mm U.FL-to-standard-SMA-female pigtail**. Use the P1 front and rear shells together. P0 files and the separate V-series housing are not interchangeable with this revision.

This is a prototype engineering release. The purchased pigtail variant is confirmed; the listing does not provide a full fitting/hinge mechanical drawing. The corresponding parameters and reference bodies are explicitly marked unconfirmed rather than presented as exact manufacturer CAD.

## Hardware and evidence

| Item | Confirmed basis | Detail still to check on arrival |
|---|---|---|
| [Pigtail, AliExpress 1005009812335103](https://www.aliexpress.com/item/1005009812335103.html) | User confirms 10 cm, U.FL to standard SMA female. Listing identifies RF1.13 cable. | Usable cable length between terminations, bulkhead thread length/flats, nut/washer sizes, plug height and supplier minimum bend radius. |
| [Telescopic antenna, AliExpress 1005007806214529](https://www.aliexpress.com/item/1005007806214529.html) | Listing dimension image: 105 mm collapsed overall, 310 mm extended overall, 9 mm diameter; hinged base. | Hinge centre relative to coupling face and separate rod length. Photo shows a centre pin; confirm actual mating hardware, as listing connector wording is inconsistent. |
| J3 / FM_ANT | Existing KiCad footprint at mechanical XY 57.395, 66.550. Supplied STEP cylindrical mating axis is **58.155, 66.550**. | Actual mated U.FL plug geometry. PCB and J3 placement are unchanged. |

Cached supplier images are intentionally excluded from the public source tree;
the source product links above remain the reproducible reference. The electrical
listing's broad frequency marketing claim is not used as an antenna-performance guarantee.

## Mount, stowage and load path

The SMA fitting exits the **upper left side at Y = 96 mm, Z = -9 mm**, with its outer mounting face at X = -10.5 mm. This keeps the lead short and puts the large external metal assembly far from the BM83 antenna at the lower right.

The rear shell has a 12.8 mm diameter reinforced mounting pod, a **6.8 mm through-hole**, a 0.35 mm entrance lead-in, and an internal 10 mm diameter fitting recess. The resulting flat clamping land is 3.0 mm thick. The hole assumes the standard nominal 6.35 mm SMA thread; nut and washer bodies are conservative circular envelopes. Confirm the available threaded length accommodates the land, washer and full nut engagement. The circular hole currently relies on the tightened washer/nut for rotational restraint; a keyed flat must follow the delivered fitting's actual dimensions.

The intended structural path is antenna → bulkhead fitting → washer/nut and reinforced rear shell. Antenna torque must not be reacted by twisting the coax or pulling J3. Tighten the bulkhead while holding its body, then connect the U.FL lead. Pull-out, torque and drop strength remain physical test items.

The antenna folds downward along the left side into two **open outward-facing saddles at Y = 45 and 72 mm**. Saddle clearance radius is 4.85 mm, giving 0.35 mm nominal radial allowance around the 9 mm antenna envelope. These are resting guides, not locking clips. Lift/swing the antenna outward to deploy it; remove the detachable antenna for the smallest pocket envelope.

The hinge offset is an explicit **12 mm provisional parameter** measured outward from the panel face. Because the supplier gives only overall lengths, the full 105 mm is conservatively reserved as a rod extending from that provisional pivot; it is not claimed to be the actual rod length. The conservative folded envelope may project slightly below the housing. The 310 mm extended envelope is supplied in a separate STEP assembly. Adjust the hinge offset and saddles after measuring the hardware rather than bending the antenna to suit the print.

The resulting **reserved folded envelope is approximately 94.6 x 122.2 x 46.8 mm** (width x height x depth including the knob). The manufactured housing including empty side saddles is approximately 90.1 x 120.9 x 46.8 mm. These are mesh/envelope dimensions, not a promise of the exact purchased-antenna outline; see `review/P1_envelope_dimensions.json`. Grey antenna bodies in the review images are conservative clearance representations. The public package records the extended-envelope dimensions rather than redistributing a fit-check assembly that embeds third-party component geometry.

## Internal cable route

The route starts on the actual J3 mating axis, exits toward the right, bends around the fixed PCB edge, and crosses the upper board back above the battery guard to reach the left bulkhead. It avoids the battery pouch, the speaker and the lower-right Bluetooth antenna region. The original P0 dummy coax and unused tall guides are removed.

The centreline uses straight segments joined by tangent **4 mm radius circular bends**, with a 1.13 mm cable envelope and 0.4 mm additional radial clearance. Both shells are relieved where needed; two supported guide locations follow the route. These guides control placement but are not a qualified tensile strain-relief clamp. The PCB must be lowered with the wire seated and visible, never used to force a loose wire into place.

The generated centreline is **86.78 mm**, leaving **13.22 mm** within the nominal 100 mm lead. `exports/P1/antenna_geometry.json` records the exact path and guide positions. That remainder is a length budget for termination differences and service movement, not guaranteed free slack: confirm how the seller measures the cable and the real minimum bend radius. If the actual cable cannot follow the route freely, change the route or lead length; do not load the U.FL connector to close the shells.

## Checks and limits

`review/clearance_review_P1.json` checks the revised shells against hardware references, printed parts and explicit corridors. It includes seven collapsed-antenna poses from 0 to 90 degrees at 15-degree intervals and the straight outward extended envelope. These are discrete pose checks, not a certified continuous three-dimensional hinge sweep.

`review/antenna_check_P1.json` separately checks the new cable/fitting envelopes against the PCB, display, battery, retainers, screws and other adjacent hardware. Cable connection at its own end fittings is intentional and excluded. This avoids treating an empty housing-only cable corridor as proof that the wire clears the electronics.

The RF review uses conservative distances from the supplied BM83 trace bounds to the added metal envelopes, including cable shielding and deployed antenna poses. The minimum for the newly added antenna hardware is **48.17 mm**; unchanged original fasteners retain their P0 separation values (minimum 18.32 mm). [Microchip recommends at least 15 mm from the onboard trace antenna to external metal for best range](https://onlinedocs.microchip.com/oxy/GUID-414904F5-364E-4377-B959-9226AD29D6A9-en-US-7/GUID-495EA464-310A-41EC-A892-5E46727B10FC.html). Geometric spacing does not replace Bluetooth/FM tests with the antenna folded, extended and held in the hand.

Other P0 validation limits remain, including print fit, display FPC routing, switch stroke/return, purchased inserts, battery leads, acoustics and manufacturing-process qualification. P1 adds actual antenna accommodation; it is not a tooling release.

## P1 verification result

The final reviewed exports report no collisions in the screened assembly pairs, all 28 explicit corridor/pose-to-shell checks are clear, and the 57 potentially adjacent cable/hardware pairs have zero overlap. All eight STL files are watertight, consistently wound and have one connected body. The new antenna hardware passes the conservative 15 mm RF spacing check. These results apply to the modelled nominal envelopes and the documented check methods; the unresolved physical fitting and performance items above remain open.

## Assembly and editable files

1. Verify the antenna and SMA female pigtail mate correctly without an adapter. Measure fitting thread length, flange/washer, hinge offset and cable length convention.
2. Install the SMA bulkhead in the rear shell's flat land. Hold its body while tightening the washer/nut; do not twist the coax.
3. Fit the speaker, battery and guard as described in the P0 report. Lay the coax along the P1 guide path above the guard, keeping its bends smooth.
4. Mate U.FL vertically onto J3 with the PCB accessible. Set the PCB into the front shell and check the cable crosses its right edge freely. Support the shells during service rather than suspending one from the pigtail. The short lead limits opening distance: release it from the open guides and disconnect U.FL before fully separating the shells. Use an assembly nest for the front and support the rear close to it while mating the lead.
5. Close the shells while observing the lead and screw locations. Check return/rotation of the controls, port/card access and absence of cable pinching.
6. Fit the antenna, confirm its hinge plane aligns with the saddles, then test folded, released and extended positions. Verify retention and radio performance before normal use.

The native model is `scripts/antenna_p1.py`, which extends `scripts/housing.py`; its antenna dimensions are in `antenna-P1.json`, with base dimensions in `parameters.json`. Run with the supplied requirements in a Python 3.12 environment:

```powershell
python Mechanical/scripts/antenna_p1.py
python Mechanical/scripts/verify_p1.py
python Mechanical/scripts/check_antenna_p1.py
python Mechanical/scripts/render_p1.py
```

The `--cached-base` option is an iteration shortcut requiring a local P0 BREP
inventory. The normal rebuild uses the editable base model. A full strict
hardware-reference rebuild requires the locally obtained component models
documented in `REFERENCE_GEOMETRY.md`; frozen transformed references and
fit-check assemblies are not redistributed. The public package contains the
project-owned housing STEP, individual parts/STLs and recorded QA results; all
STL units are mm and coordinates are assembled positions.

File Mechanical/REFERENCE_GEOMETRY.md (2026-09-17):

# Mechanical reference geometry

The kiku enclosure is project source, but a complete mechanical fit review also
uses component 3D models referenced by the KiCad PCB. Those component models do
not all have a single documented redistribution licence, so the public source
tree deliberately separates **project-owned outputs** from **local fit-check
inputs**.

## What is public

The public tree includes:

- `Walkman - Blobject.kicad_pcb`, the electrical/mechanical board source of truth;
- `reference/board_datums.json`, generated from that board by
  `scripts/extract_board.py`;
- `reference/pcb_bare.step`, which contains project board geometry without the
  populated component-model bundle;
- `reference/component_envelopes.json`, numeric provenance/fidelity and bounding
  metadata from the last reviewed reference set;
- the project-owned enclosure/part STEP and STL outputs;
- machine-readable clearance/interface results and project-generated review
  material.

The currently reviewed board datums contain 133 footprint-model references: 112
to the KiCad 9 model library and 21 to the local `3dmodels/` directory. The
source-audit command below derives its result from `board_datums.json`, so a board
change is not hidden by these documentation counts.

The public tree does **not** include:

- the local `3dmodels/` component bundle;
- transformed/frozen `REF_*.brep` component solids;
- `reference/pcb_populated.step`;
- P0/P1 fit-check assembly STEP files that embed those component solids;
- V-series `kiku_fit_check_with_pcb_v*.step` outputs for the same reason.

These exclusions are intentional. Converting or transforming a third-party model
to BREP/STEP does not make it a project-owned asset.

## Obtaining the local inputs

`reference/board_datums.json` records the exact KiCad model expression for every
footprint. There are two input classes:

1. `${KICAD9_3DMODEL_DIR}/...` models. Install the matching KiCad 9 3D-model
   libraries and use them under their published licence terms.
2. `${KIPRJMOD}/3dmodels/...` models. Obtain the applicable model from the
   original manufacturer, KiCad/component-library or other recorded publisher
   under that source's terms, then place it under `3dmodels/` using the filename
   recorded by the board. The public repository does not provide or relicence it.

The public metadata records model expressions, transforms and the reviewed final
bounding boxes, but it does not invent missing upstream URLs, licences or model
revision hashes. For an exact repeat of the historical reference QA, use the same
upstream model revision and compare the regenerated `component_envelopes.json`
against the checked-in reviewed metadata. A different model that merely has the
same filename must not be assumed equivalent.

The D3 reference is the documented exception: the reviewed model intentionally
uses a conservative synthetic allowance when its KiCad 0201 STEP is unavailable.
That fallback is project-generated and is labelled `UNVERIFIED` in
`component_envelopes.json`.

If KiCad is installed somewhere other than the default Windows KiCad 9 path, set
`KICAD9_3DMODEL_DIR` to its `3dmodels` directory before running the reference
tools.

The checked-in bare board STEP can be regenerated without component models. With
KiCad 9, the reviewed command is:

```powershell
kicad-cli pcb export step --board-only --force `
  --user-origin 72.11x157.90mm `
  -o Mechanical/reference/pcb_bare.step `
  "Walkman - Blobject.kicad_pcb"
```

The explicit user origin maps the KiCad board outline to the mechanical
coordinate system (X = 0..60 mm, Y = 0..105 mm). KiCad STEP serialisation is not
byte-stable across exports, so validate geometry rather than file SHA alone. The
reviewed KiCad 9.0.2 export and the checked-in STEP both report one solid with
volume 9420.049197045 mm^3 and bounds `[0, 0, 0, 60, 105, 1.51]` mm.

From the repository root, audit the local model set with:

```powershell
python Mechanical/scripts/reference_geometry.py --check-sources
```

The command fails if any exact source required by the reviewed reference set is
missing, other than the documented D3 allowance. It prints the unresolved board
model expression so the missing file is obtained from its original publisher
rather than copied from this repository.

After the source audit passes, an optional local transformed cache can be made
with:

```powershell
python Mechanical/scripts/reference_geometry.py --freeze-local
```

This writes transformed component BREPs under `Mechanical/reference/frozen/`.
They are ignored by Git and must not be added to a public package. Their purpose
is only to make subsequent local CAD iterations independent of machine-specific
library paths.

## Rebuilding and validating

For the P0/P1 Mame engineering revisions, a full strict reference rebuild uses:

```powershell
python Mechanical/scripts/reference_geometry.py --check-sources
python Mechanical/scripts/housing.py
python Mechanical/scripts/verify.py
python Mechanical/scripts/interface_review_p0.py
python Mechanical/scripts/antenna_p1.py
python Mechanical/scripts/verify_p1.py
python Mechanical/scripts/check_antenna_p1.py
```

Those commands may locally generate populated/frozen fit-check geometry. The
geometry is validation input/output, not redistributable project source.

The public packaging commands are intentionally different:

```powershell
python Mechanical/scripts/package_p0.py
python Mechanical/scripts/package_p1.py
```

They consume the checked-in project-owned exports and recorded QA reports, and
do not require or package third-party model solids. This keeps the public package
reproducible from a stripped public checkout without weakening the previously
performed strict hardware-reference checks.

For the newer V-series housing generator, `scripts/build_housing.py` performs
collision tests against a locally generated `reference/pcb_populated.step` and
may generate `kiku_fit_check_with_pcb_v*.step` review assemblies. Those fit-check
STEPs are local-only because they embed the populated reference. A fresh full V8
fit validation therefore also requires the same local third-party model setup.
Do not substitute the bare PCB for those component collision checks or interpret
a housing-only build as equivalent validation.

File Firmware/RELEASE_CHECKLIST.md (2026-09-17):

# kiku release checklist

This document is the release gate for production firmware. A firmware build is
not a production release until every software gate passes and every applicable
hardware gate is signed off on the exact PCB/BOM/enclosure revision being sold.

## Automated software gate

Run from the repository root:

```text
python Firmware/tools/release_check.py --require-clean
```

The gate runs native regression tests, clean release and debug cross-builds,
checks first-party static stack frames, runs `git diff --check`, rebuilds the
release image last, and emits `Firmware/build/kiku-build-manifest.json` with
SHA-256 hashes and the exact compiler/Git identity.

Release only the final `kiku.hex`/`kiku.bin` that matches that manifest.

## Required functional regression

- Cold boot from battery at low, nominal and near-full cell voltage.
- 24-hour watchdog/reset soak with no unexplained resets.
- Bluetooth: first pairing, power-cycle reconnect, phone-side disconnect and
  reconnect, out-of-range/re-entry, AVRCP controls, metadata changes, pause /
  resume, and repeated source switching. The exact golden radio must sustain at
  least 250 successful physical `0x5D` metadata responses (comfortably beyond
  the former ~90-response failure depth) with no rising timeout/backpressure
  trend, while A2DP and AVRCP remain connected. Exercise multiple NEXT, PREV and
  source-side track changes and verify title/artist/album change atomically with
  no stale-field mixing.
- FM: all presets, manual tuning, seek in both directions, RDS/no-RDS stations,
  weak-signal behaviour, volume adjustment and source switching.
- microSD: empty socket, hot insert, hot removal during idle and playback,
  reinsertion, FAT32 cards at supported sizes, long filenames, malformed MP3,
  truncated MP3, unsupported files and a library larger than the indexed limit.
- Audio outputs: headphones, speaker, AUTO and BOTH modes; plug/unplug while
  playing; maximum-volume clipping/noise check.
- UI: every screen/menu item, encoder/button short/long press, power-save mode,
  SD shuffle, error/diagnostics screen and text truncation with long metadata.
- Settings: save, power loss during/after save, corrupt settings file and
  migration from the legacy development filename.

## Power / charging release blockers

- The current Rev-A USB-C fault must be electrically resolved. Firmware has
  already observed the BQ25895 alive while reporting no valid VBUS with USB-C
  connected; do not release hardware until J1/F1/protection/U2 VBUS is fixed.
- Verify the final board cannot negotiate or expose the 5-V-class VBUS
  protection to >5 V at any point, including the interval before MCU firmware
  starts. Rev-A currently relies partly on early BQ25895 configuration.
- Resolve the observed MAX17048-vs-BQ25895 battery-voltage disagreement and
  verify SOC against a calibrated DMM across charge/discharge cycles.
- Freeze the exact production cell, charge-current limit, thermistor/TS policy
  and enclosure thermal limits before enabling a production charge-current
  policy.

## Bluetooth production gate

- Use a compatible MSPK2 v1.3-or-newer **SPP Host-Mode** radio image. The v1.2
  development module is not a production golden unit: Microchip documents and
  fixes in v1.3 the defect where firmware stops responding to UART `0x4A` after
  many requests.
- Freeze and archive the exact BM83 radio firmware and Config Tool image used in
  production, including SHA-256 hashes, outside the public source repository.
- Record BM83 UART/FW/EEPROM/DSP versions from a golden unit.
- Confirm Host MCU mode, 115200 UART, A2DP sink, AVRCP and 48-kHz/24-bit I2S
  host-clock settings match the firmware contract.
- Disable OTA DFU if it is not an intentional product feature. If enabled,
  provision a non-default production secret outside Git and verify that no
  development/example key ships in the golden configuration.
- Verify pairing records survive MCU/BM83 resets and full battery disconnect.

## Manufacturing / programming gate

- Program only from the release manifest and verify flash after programming.
- Record unit serial/lot, firmware manifest hash and PCB revision.
- Run a fixture self-test covering display, controls, SD, codec/headphones,
  speaker, FM, Bluetooth, fuel gauge and charger status.
- Decide and document SWD access policy for shipped units (serviceable vs
  locked). Do not enable readout protection until the recovery/service process
  is validated.

## Mechanical / regulatory gate

- Final enclosure must preserve BM83 antenna keep-out and FM coax clearance.
- Validate speaker/battery restraint, drop/thermal behaviour and connector
  strain relief using production materials.
- Complete applicable electrical, EMC/RF, battery transport/safety and market
  compliance work for the jurisdictions in which kiku will be sold.

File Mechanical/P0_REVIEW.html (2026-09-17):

Blobject / Mechanical design / P0

# Kiku. A softer kind of music player.

Engineering development · physical fit validation pending

Mame pairs a softly asymmetric ivory front with a muted green rear, a recessed smoked lens and distinct tactile controls. The existing PCB positions are retained. The selected speaker is LCSC C50387209; the battery envelope is 34 × 50 × 10 mm.

Housing STEPMechanical reportReference setupEditable CAD sourceGeometry checksInterface checks

77.1 × 120.9 × 46.8 mmApprox. width × height × depth including knob

1.8 mmNominal shell wall

8 partsIndividual prototype STL exports

## Three interpretations

Front, rear, profile and perspective studies. Mame was selected for its balance of character, grip and assembly space; the alternatives and scoring are documented in the report.

Mame, Nagare and Mini concepts

## The developed assembly

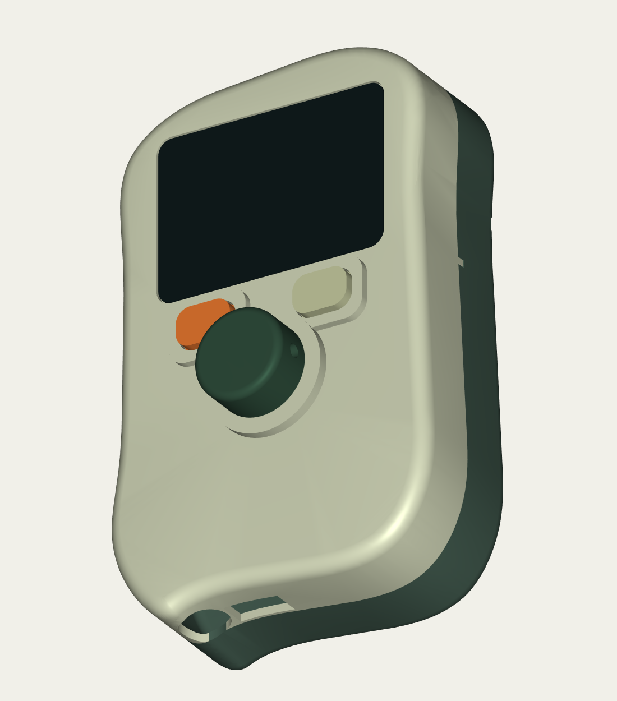
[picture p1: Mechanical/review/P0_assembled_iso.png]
Assembled perspective


Assembled perspective

Front

Front

Rear / speaker grille

Rear / speaker grille

Profile

Profile

Exploded assembly

Exploded assembly

Longitudinal section at X = 30 mm

Longitudinal section at X = 30 mm

Control section at Y = 55 mm

Control section at Y = 55 mm

Speaker section at X = 18 mm

Speaker section at X = 18 mm

Front interior

Front interior

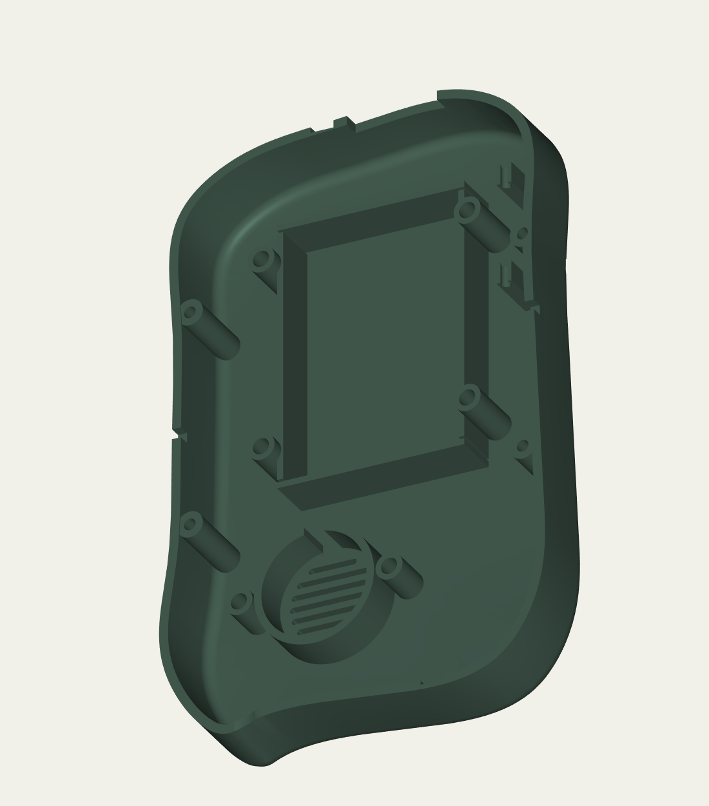
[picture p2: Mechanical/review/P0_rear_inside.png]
Rear interior


Rear interior

## Verification and next physical checks

The current geometric review found no overlaps in its screened rigid-part pairs or the explicit connector/FPC corridors. All eight STL meshes are watertight with consistent winding. Discrete control positions and added fasteners are checked separately. Surface screening does not certify minimum clearance, full containment or tolerance stacks.

Confirm the real display tail fold, switch actuation and return, purchased inserts, battery lead exit, speaker tab and sealing, FM antenna installation and RF performance before committing to use or tooling. SW1/QON is internal in this version. The report identifies the remaining moulding changes.

Dimensions are millimetres. The recorded QA used locally obtained hardware models and explicitly identified bounding envelopes; third-party model solids are not redistributed in this package. P0 is a prototype engineering package, not a production release.

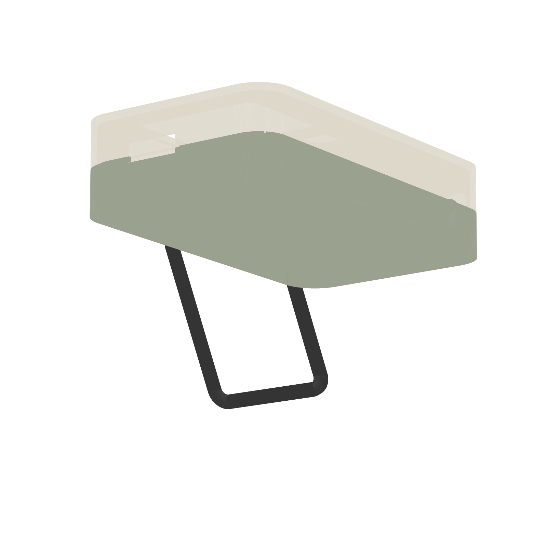
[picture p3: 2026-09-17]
Mechanical/review/kiku_housing_v7_stand_open.png

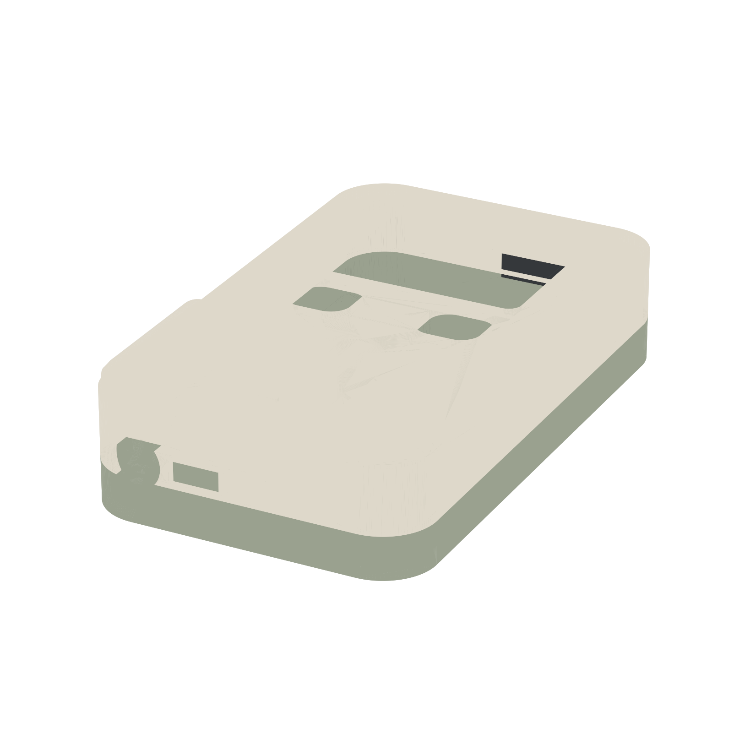
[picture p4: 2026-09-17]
Mechanical/review/kiku_housing_v5_front_3q.png

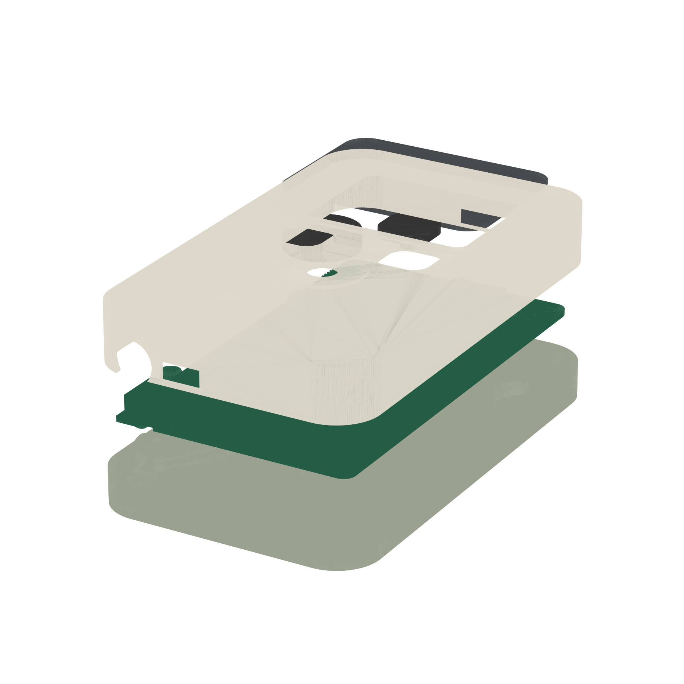
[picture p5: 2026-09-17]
Mechanical/review/kiku_housing_v2_exploded.png

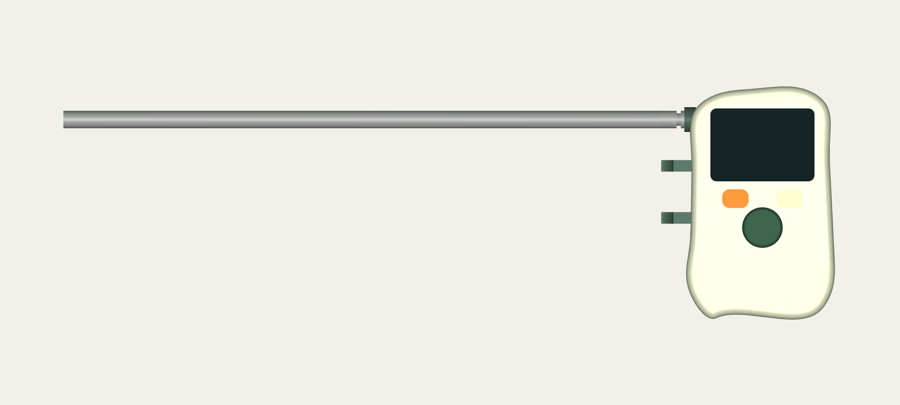
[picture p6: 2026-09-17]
Mechanical/review/P1_antenna_extended.png

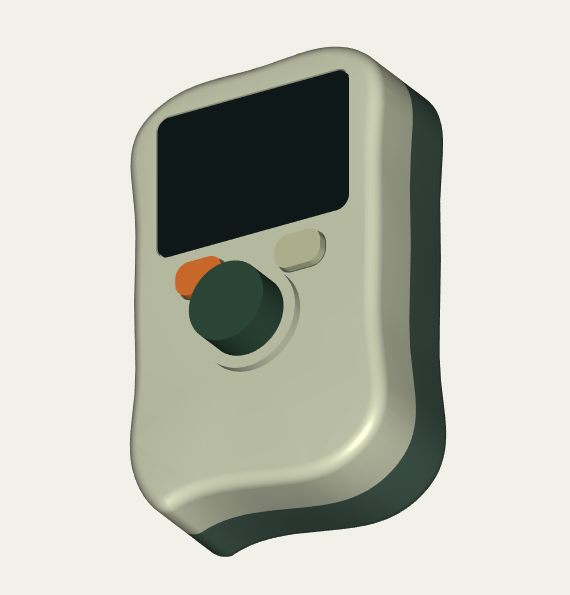
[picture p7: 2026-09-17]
Mechanical/concepts/03_Mini_iso.png

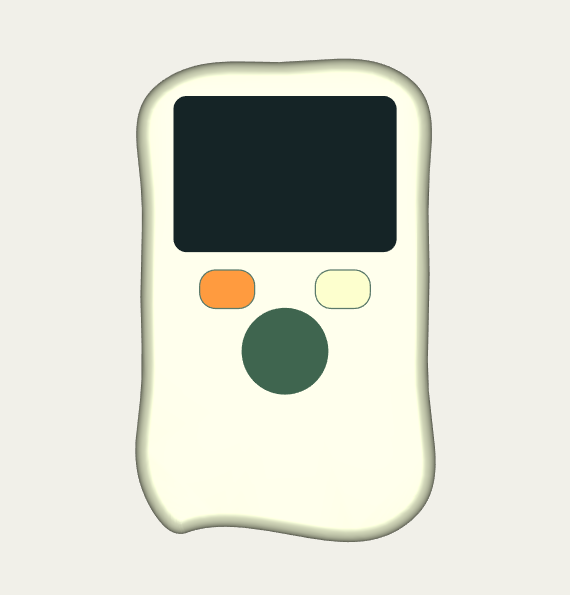
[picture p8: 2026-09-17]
Mechanical/concepts/03_Mini_front.png

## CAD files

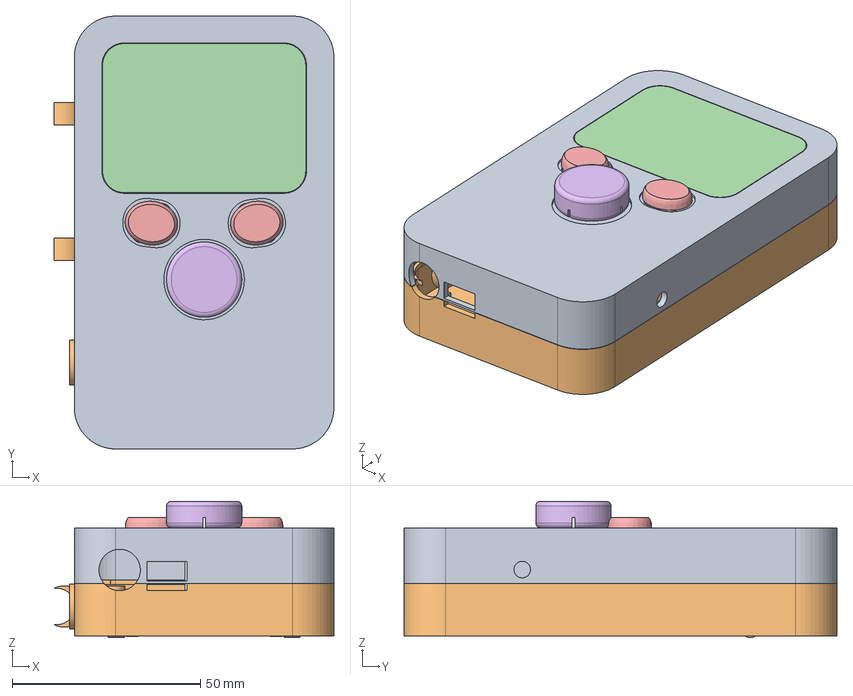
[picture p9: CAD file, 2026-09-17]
Mechanical/exports/kiku_housing_assembly_v8.step
74.4 x 115.0 x 36.2 mm

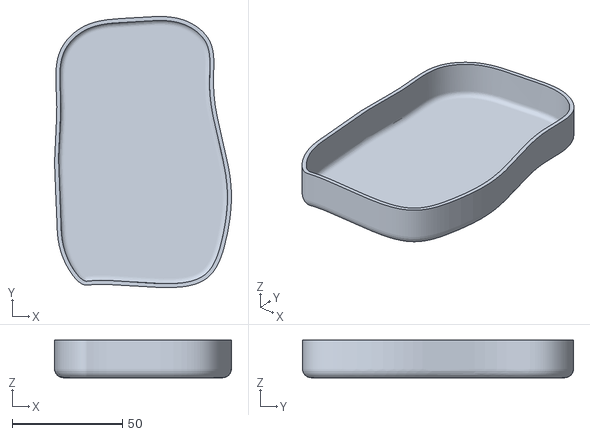
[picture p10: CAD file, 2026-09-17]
Mechanical/concepts/02_Nagare_rear_shell.stl
80.1 x 122.7 x 17.0

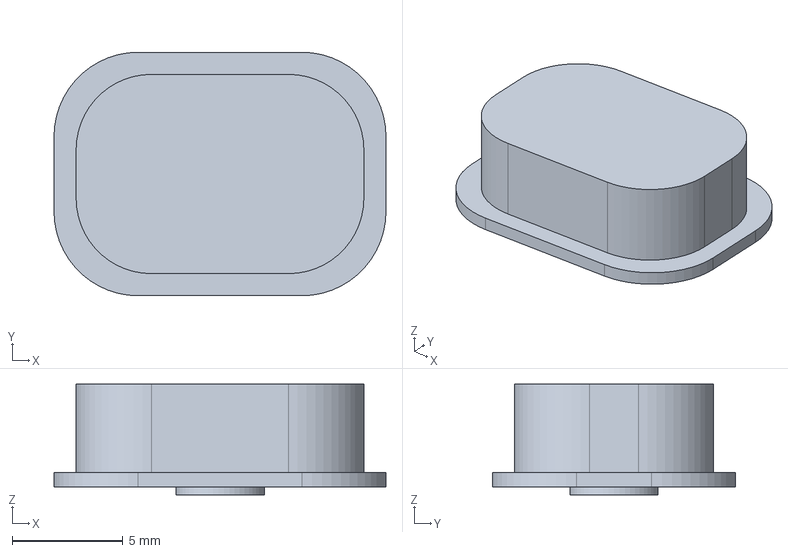
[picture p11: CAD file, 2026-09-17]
Mechanical/exports/P0/button_right.step
15.0 x 11.0 x 5.00 mm

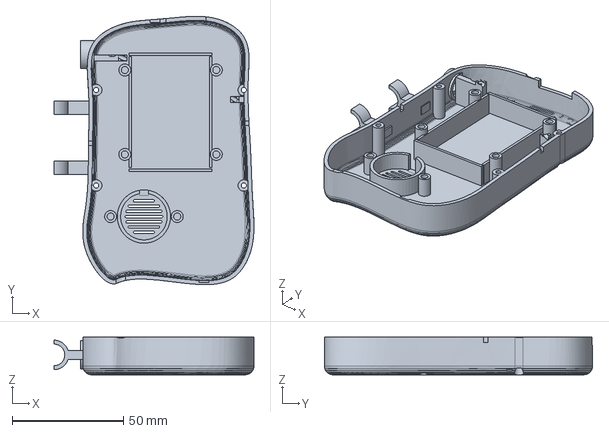
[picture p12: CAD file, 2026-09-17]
Mechanical/exports/P1/rear_shell.step
90.1 x 120.9 x 17.0 mm

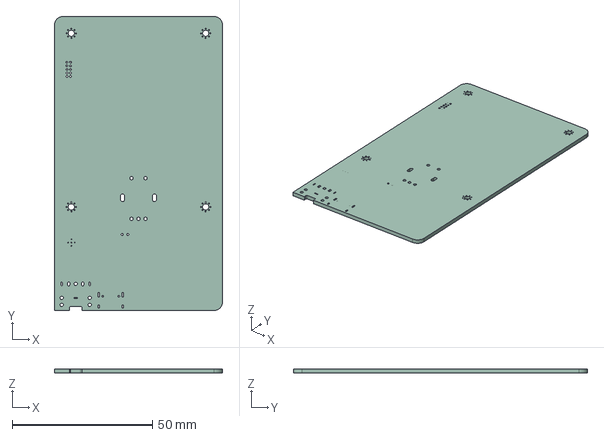
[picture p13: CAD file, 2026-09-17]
Mechanical/reference/pcb_bare.step
60.0 x 105.0 x 1.51 mm

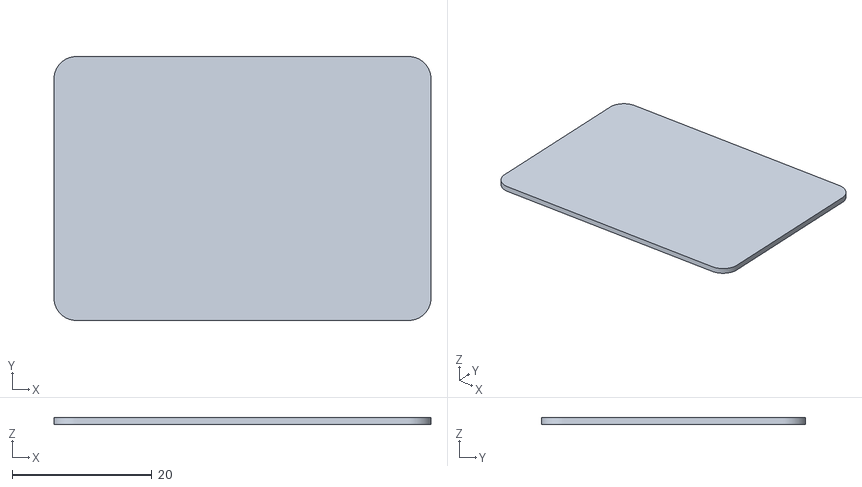
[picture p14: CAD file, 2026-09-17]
Mechanical/concepts/02_Nagare_lens.stl
54.0 x 37.8 x 1.00

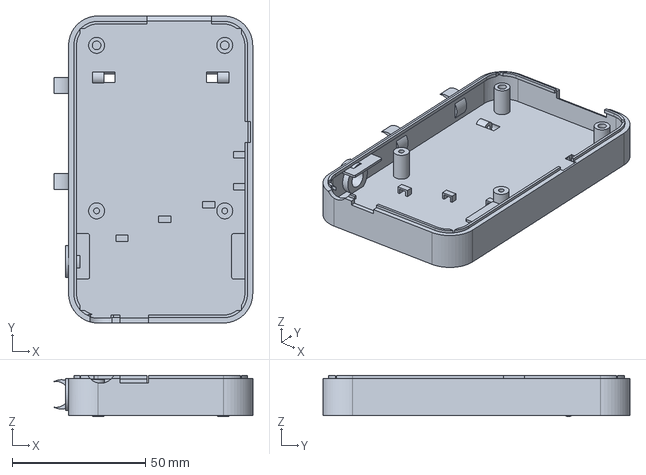
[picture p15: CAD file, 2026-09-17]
Mechanical/exports/kiku_rear_shell_smooth_stand_v8.step
74.4 x 115.0 x 15.4 mm

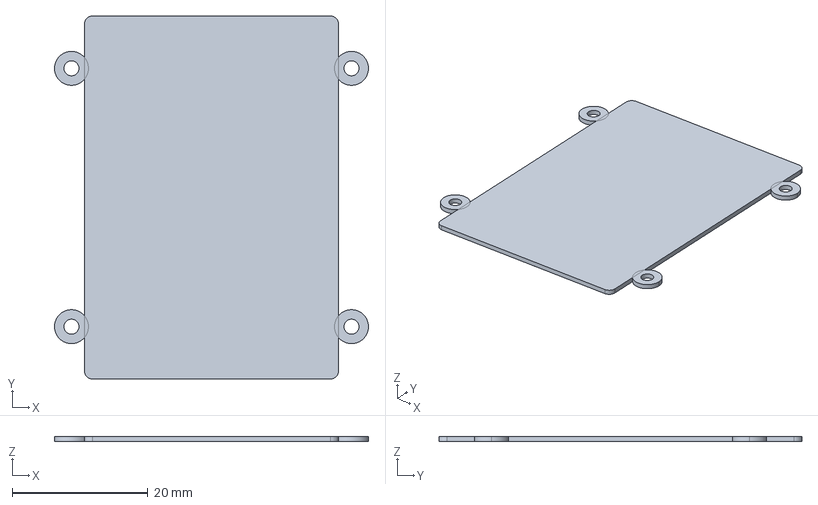
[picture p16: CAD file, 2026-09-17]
Mechanical/exports/P1/battery_guard.step
46.2 x 53.4 x 0.8 mm

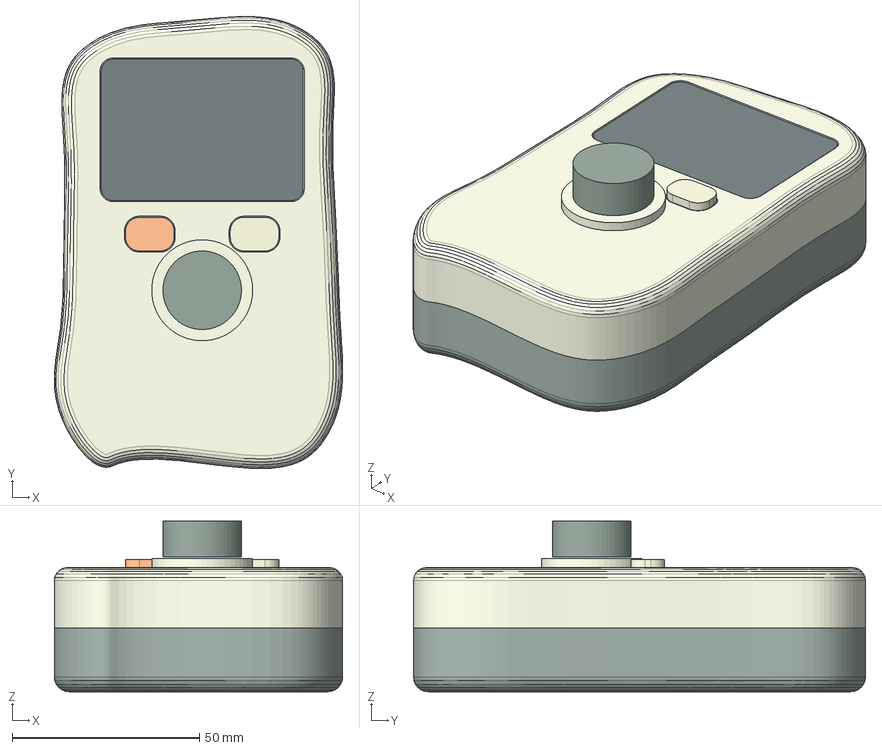
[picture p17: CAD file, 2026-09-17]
Mechanical/concepts/01_Mame.step
77.1 x 120.8 x 45.6 mm
front_shell
rear_shell
lens
button_left
button_right
encoder_knob

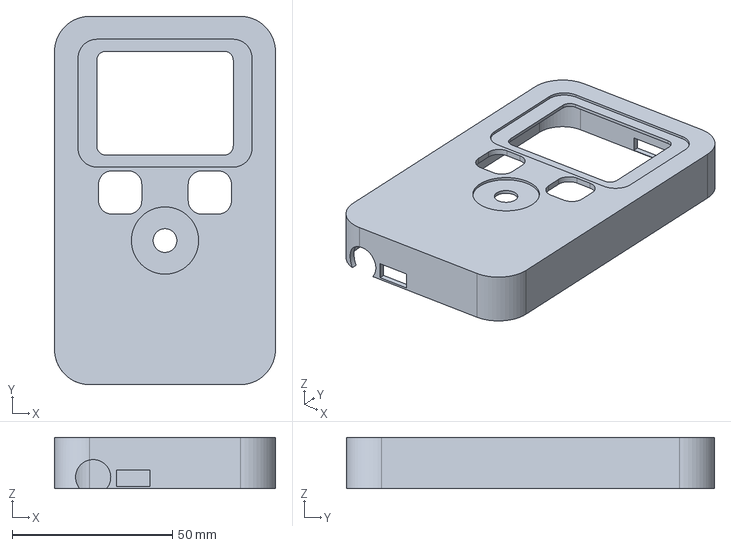
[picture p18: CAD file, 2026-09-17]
Mechanical/exports/kiku_front_shell_v1.step
69.0 x 115.0 x 15.9 mm

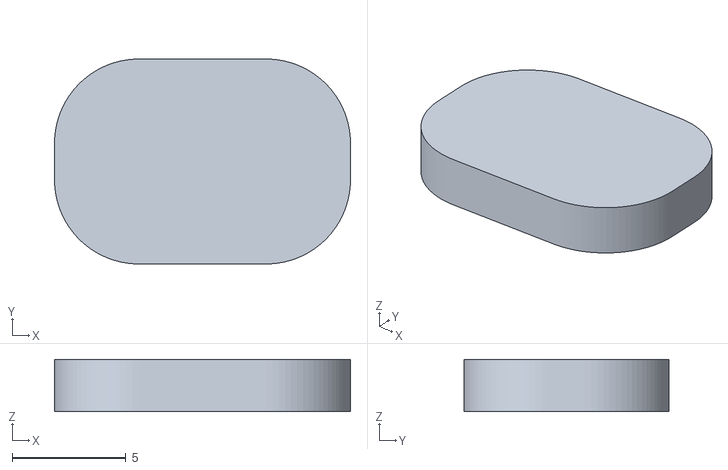
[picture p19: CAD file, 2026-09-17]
Mechanical/concepts/03_Mini_button_right.stl
13.0 x 9.00 x 2.30

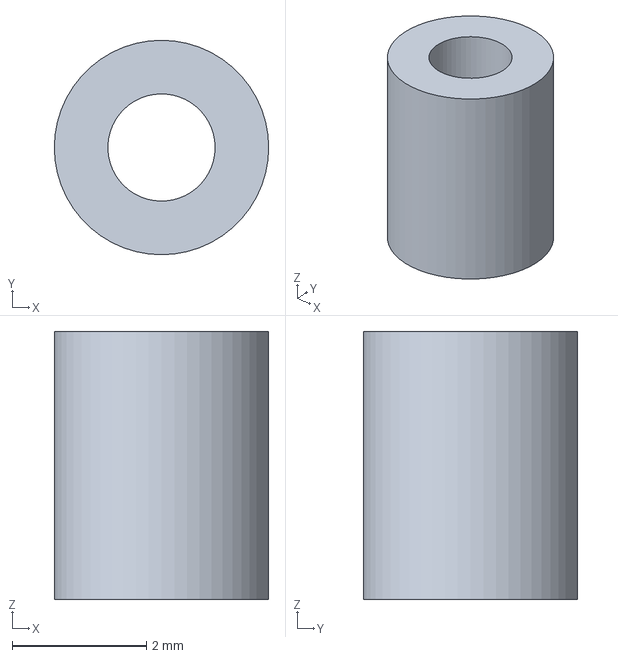
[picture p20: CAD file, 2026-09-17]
Mechanical/exports/P1/lcd_insert_0.7_72.step
3.20 x 3.20 x 4.00 mm

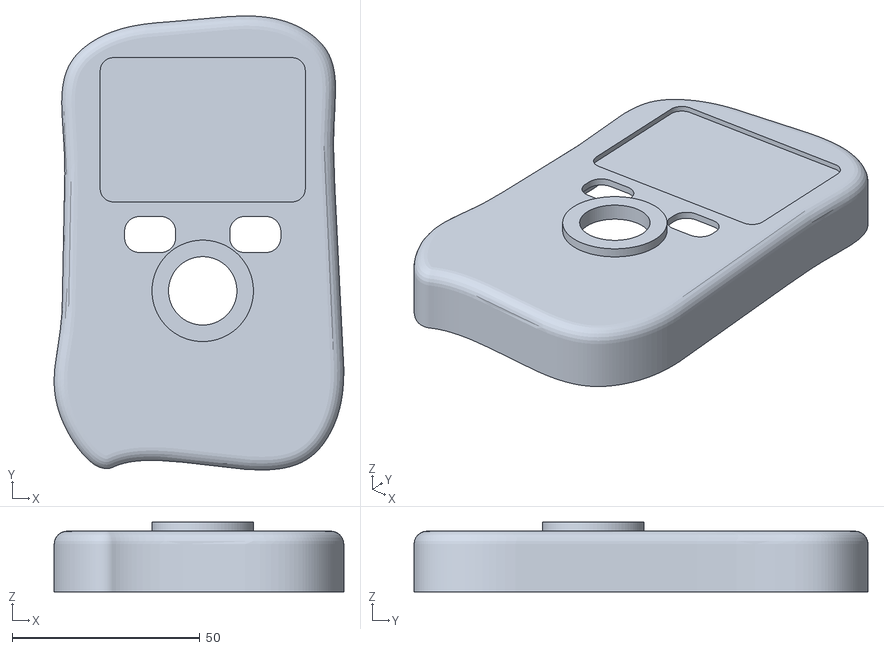
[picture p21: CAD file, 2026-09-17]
Mechanical/concepts/01_Mame_front_shell.stl
77.1 x 120.9 x 18.6

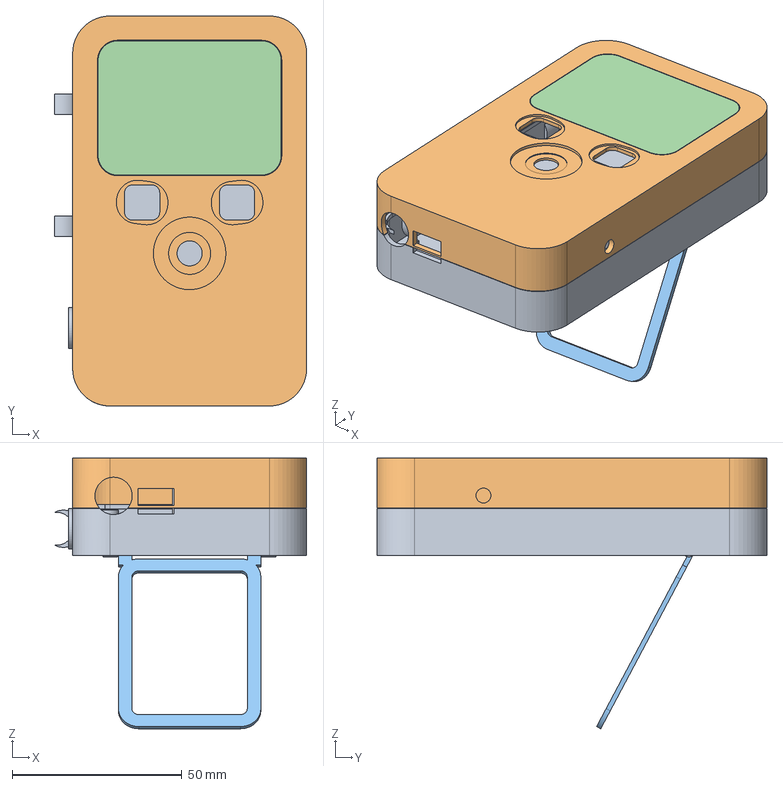
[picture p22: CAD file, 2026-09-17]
Mechanical/exports/kiku_kickstand_open_reference_v8.step
74.4 x 115.0 x 79.8 mm

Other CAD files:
Mechanical/exports/P0/button_left.step
Mechanical/exports/P0/front_shell.step
Mechanical/concepts/03_Mini_front_shell.stl
Mechanical/exports/P0/encoder_knob.step
Mechanical/concepts/01_Mame_button_left.stl
Mechanical/concepts/01_Mame_encoder_knob.stl
Mechanical/concepts/01_Mame_rear_shell.stl
Mechanical/concepts/02_Nagare.step
Mechanical/concepts/02_Nagare_button_left.stl
Mechanical/concepts/02_Nagare_encoder_knob.stl
Mechanical/concepts/02_Nagare_front_shell.stl
Mechanical/concepts/03_Mini.step
Mechanical/concepts/03_Mini_button_left.stl
Mechanical/concepts/03_Mini_encoder_knob.stl
Mechanical/concepts/03_Mini_rear_shell.stl
Mechanical/exports/P0/Kiku_P0_housing.step
Mechanical/exports/P0/PCB_insert_H5.step
Mechanical/exports/P0/PCB_insert_H6.step
Mechanical/exports/P0/PCB_insert_H7.step
Mechanical/exports/P0/PCB_insert_H8.step
Mechanical/exports/P0/PCB_screw_H5.step
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

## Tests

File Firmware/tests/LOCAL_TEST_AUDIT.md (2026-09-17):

# Local firmware test audit — 2026-09-14

The working tree contained unpublished changes to the BM83 driver, application,
FM state, renderer, platform initialization and `test_main.c`. The metadata and
connection recovery work has been retained and extended with regression tests.
The renderer uses the layout from commit `a87ce5a`, retaining the existing
button footer and partial station-name updates.

Additional ignored files found locally:

- `tests/build/fmoffs.c`, `liveoffs.c`, `offsets.c`, `target_offsets.c`, and
  `target_offsets2.c`: scratch programs that emit application/MCU structure
  offsets for debugger inspection. Their assembly and executables are generated
  artifacts; offsets must be regenerated whenever the structures change.
- `tests/build/blobject_tests.exe` and `kiku_tests.exe`: old/native test binaries.
- `BM83_tools/blobject_bm83_host_i2s1.log`: Config Tool settings export, including
  I2S master mode and 24-bit data. It is not a live UART metadata capture.
- `build/`: compiled firmware and dependency/stack-usage artifacts.
- `BM83_eeprom_0000_012f.bin` is already tracked but empty; it cannot establish
  what EEPROM configuration is actually programmed on the module.

The scratch files were left in place. Executable regressions live in
`test_main.c` and run with `python Firmware/tools/test_host.py`. The suite now
also compiles the application code and checks legacy metadata response parsing,
version-dependent commands, fallback from every browsing timeout, repeated and
out-of-order 2B RadioText, rejected corrupt text, and metadata-driven rendering.

Software checks cannot confirm reception from a physical station or phone.
On-device follow-up: tune a station that broadcasts RadioText, wait for its text
cycle, connect a phone and change songs, then disconnect/reconnect Bluetooth.
Confirm title/artist refresh and existing button actions on the restored UI.

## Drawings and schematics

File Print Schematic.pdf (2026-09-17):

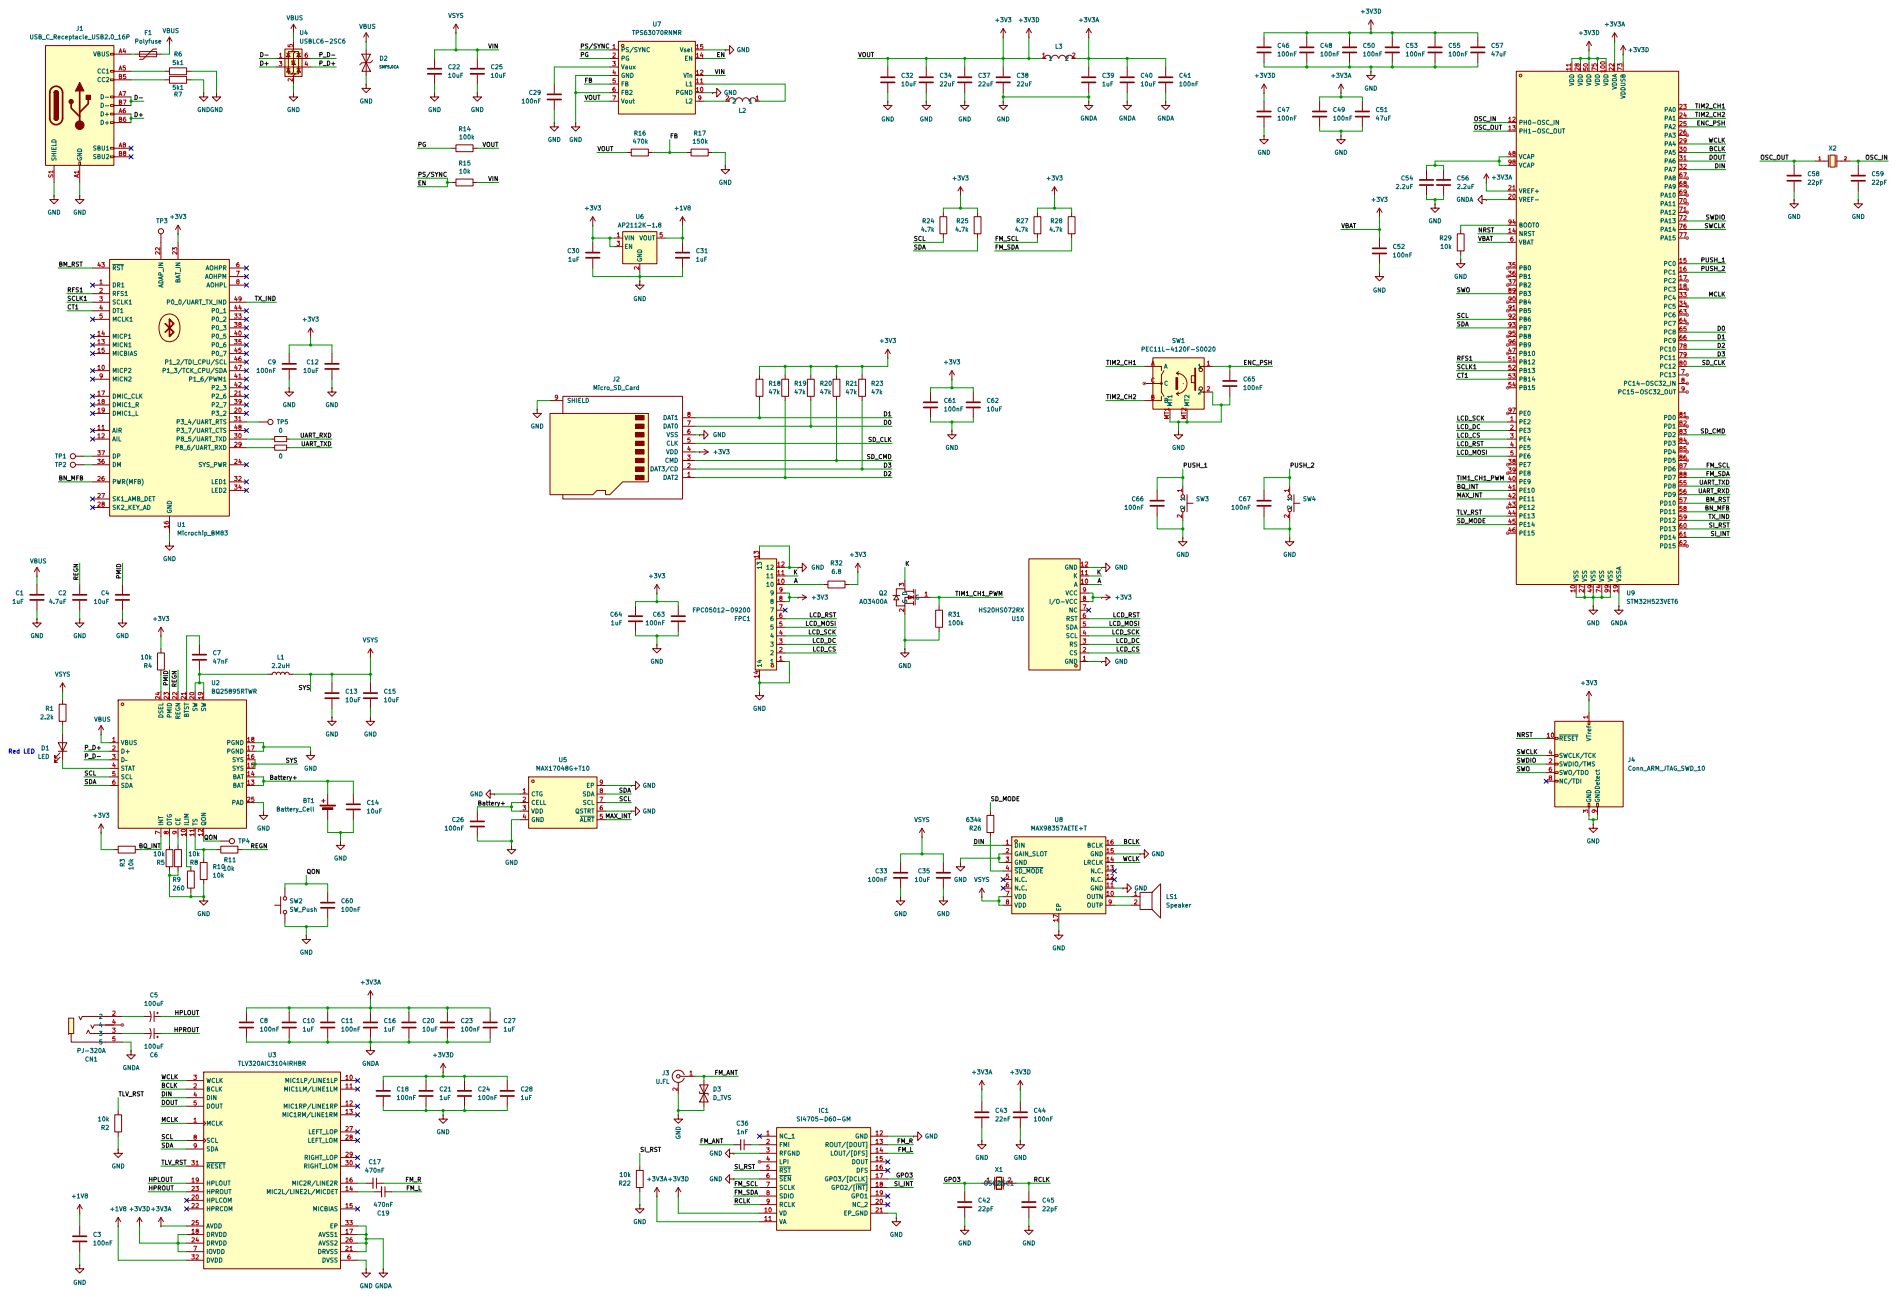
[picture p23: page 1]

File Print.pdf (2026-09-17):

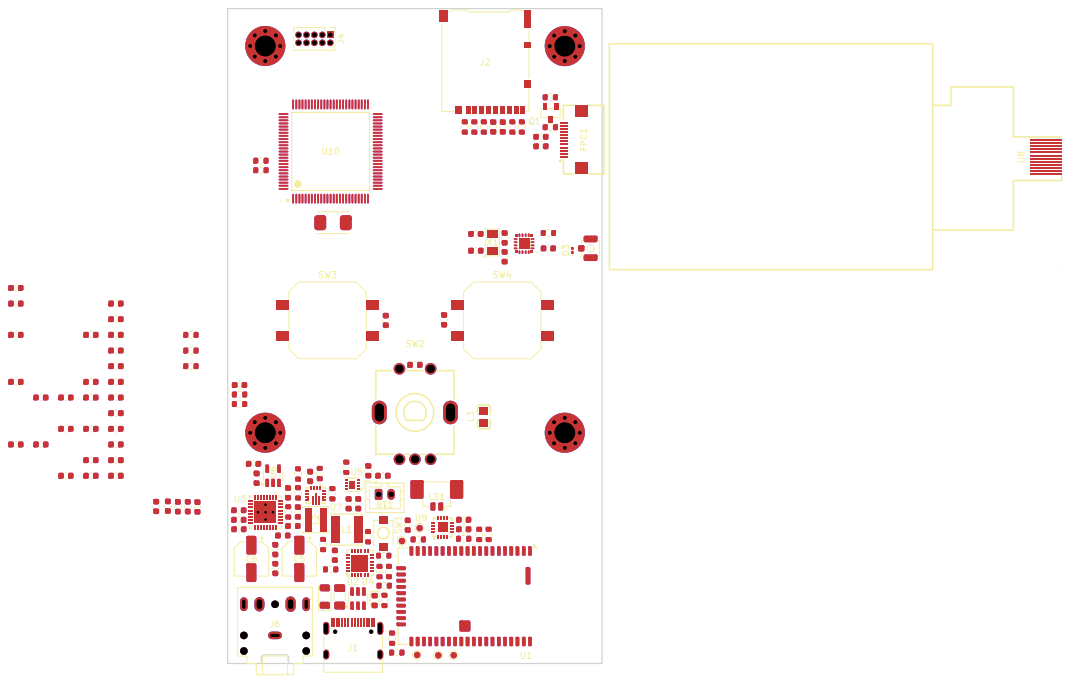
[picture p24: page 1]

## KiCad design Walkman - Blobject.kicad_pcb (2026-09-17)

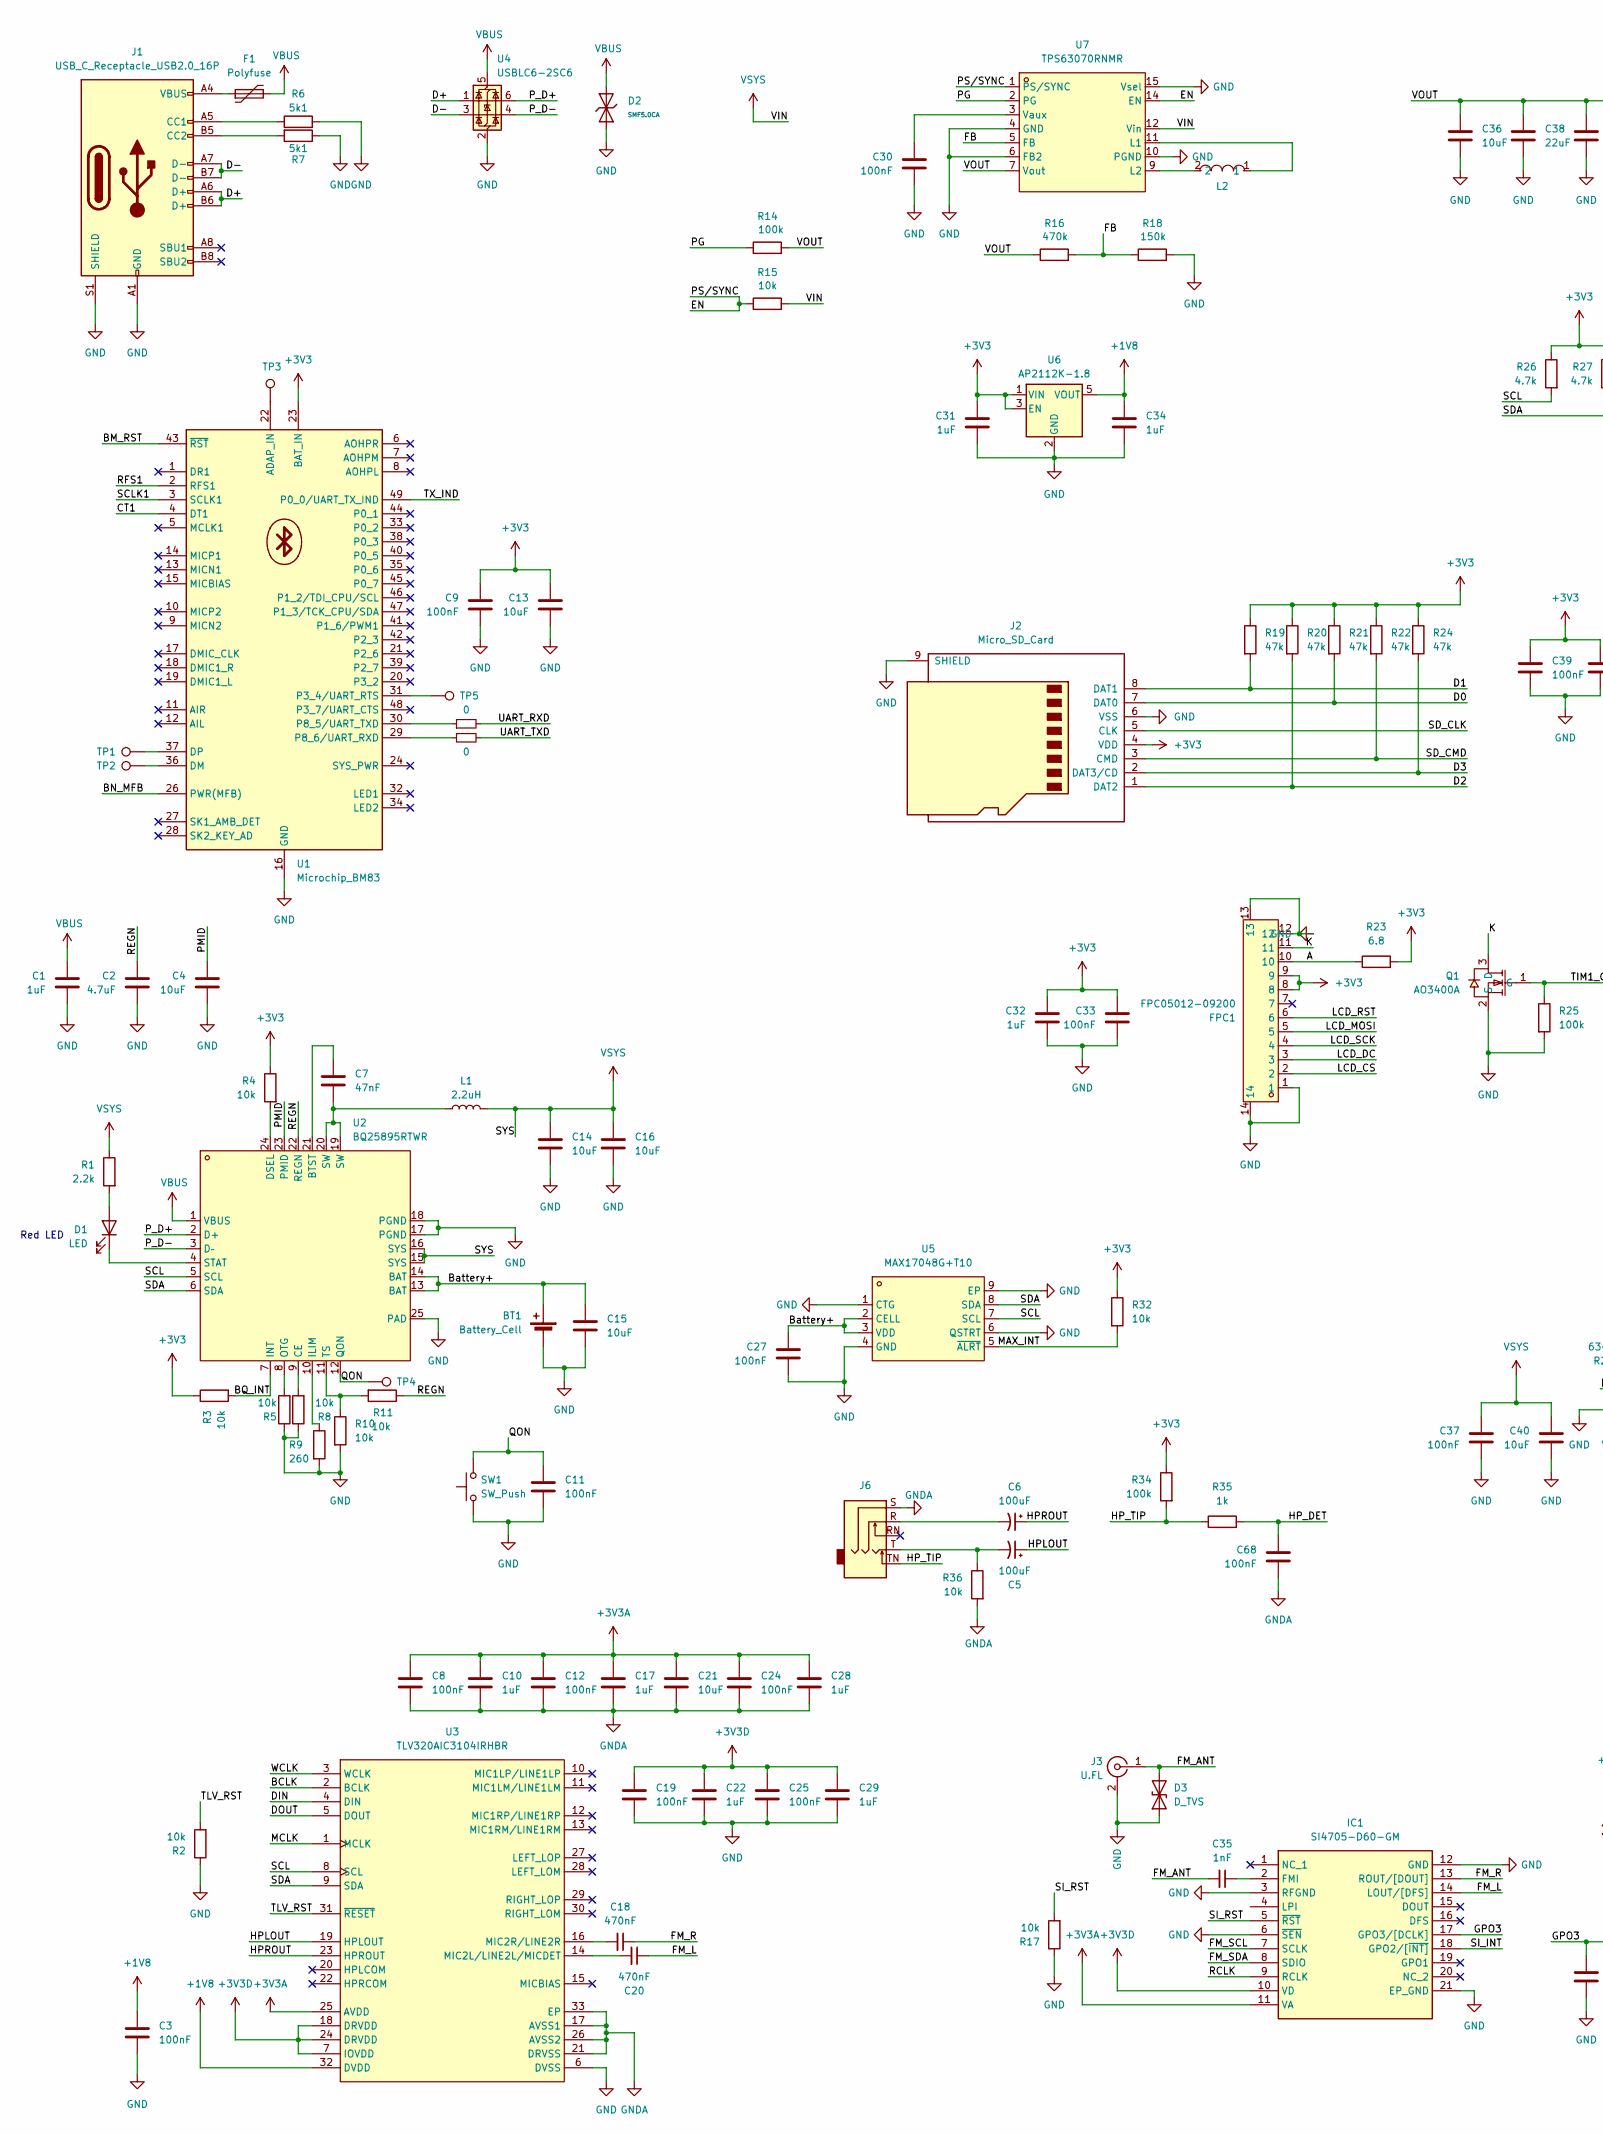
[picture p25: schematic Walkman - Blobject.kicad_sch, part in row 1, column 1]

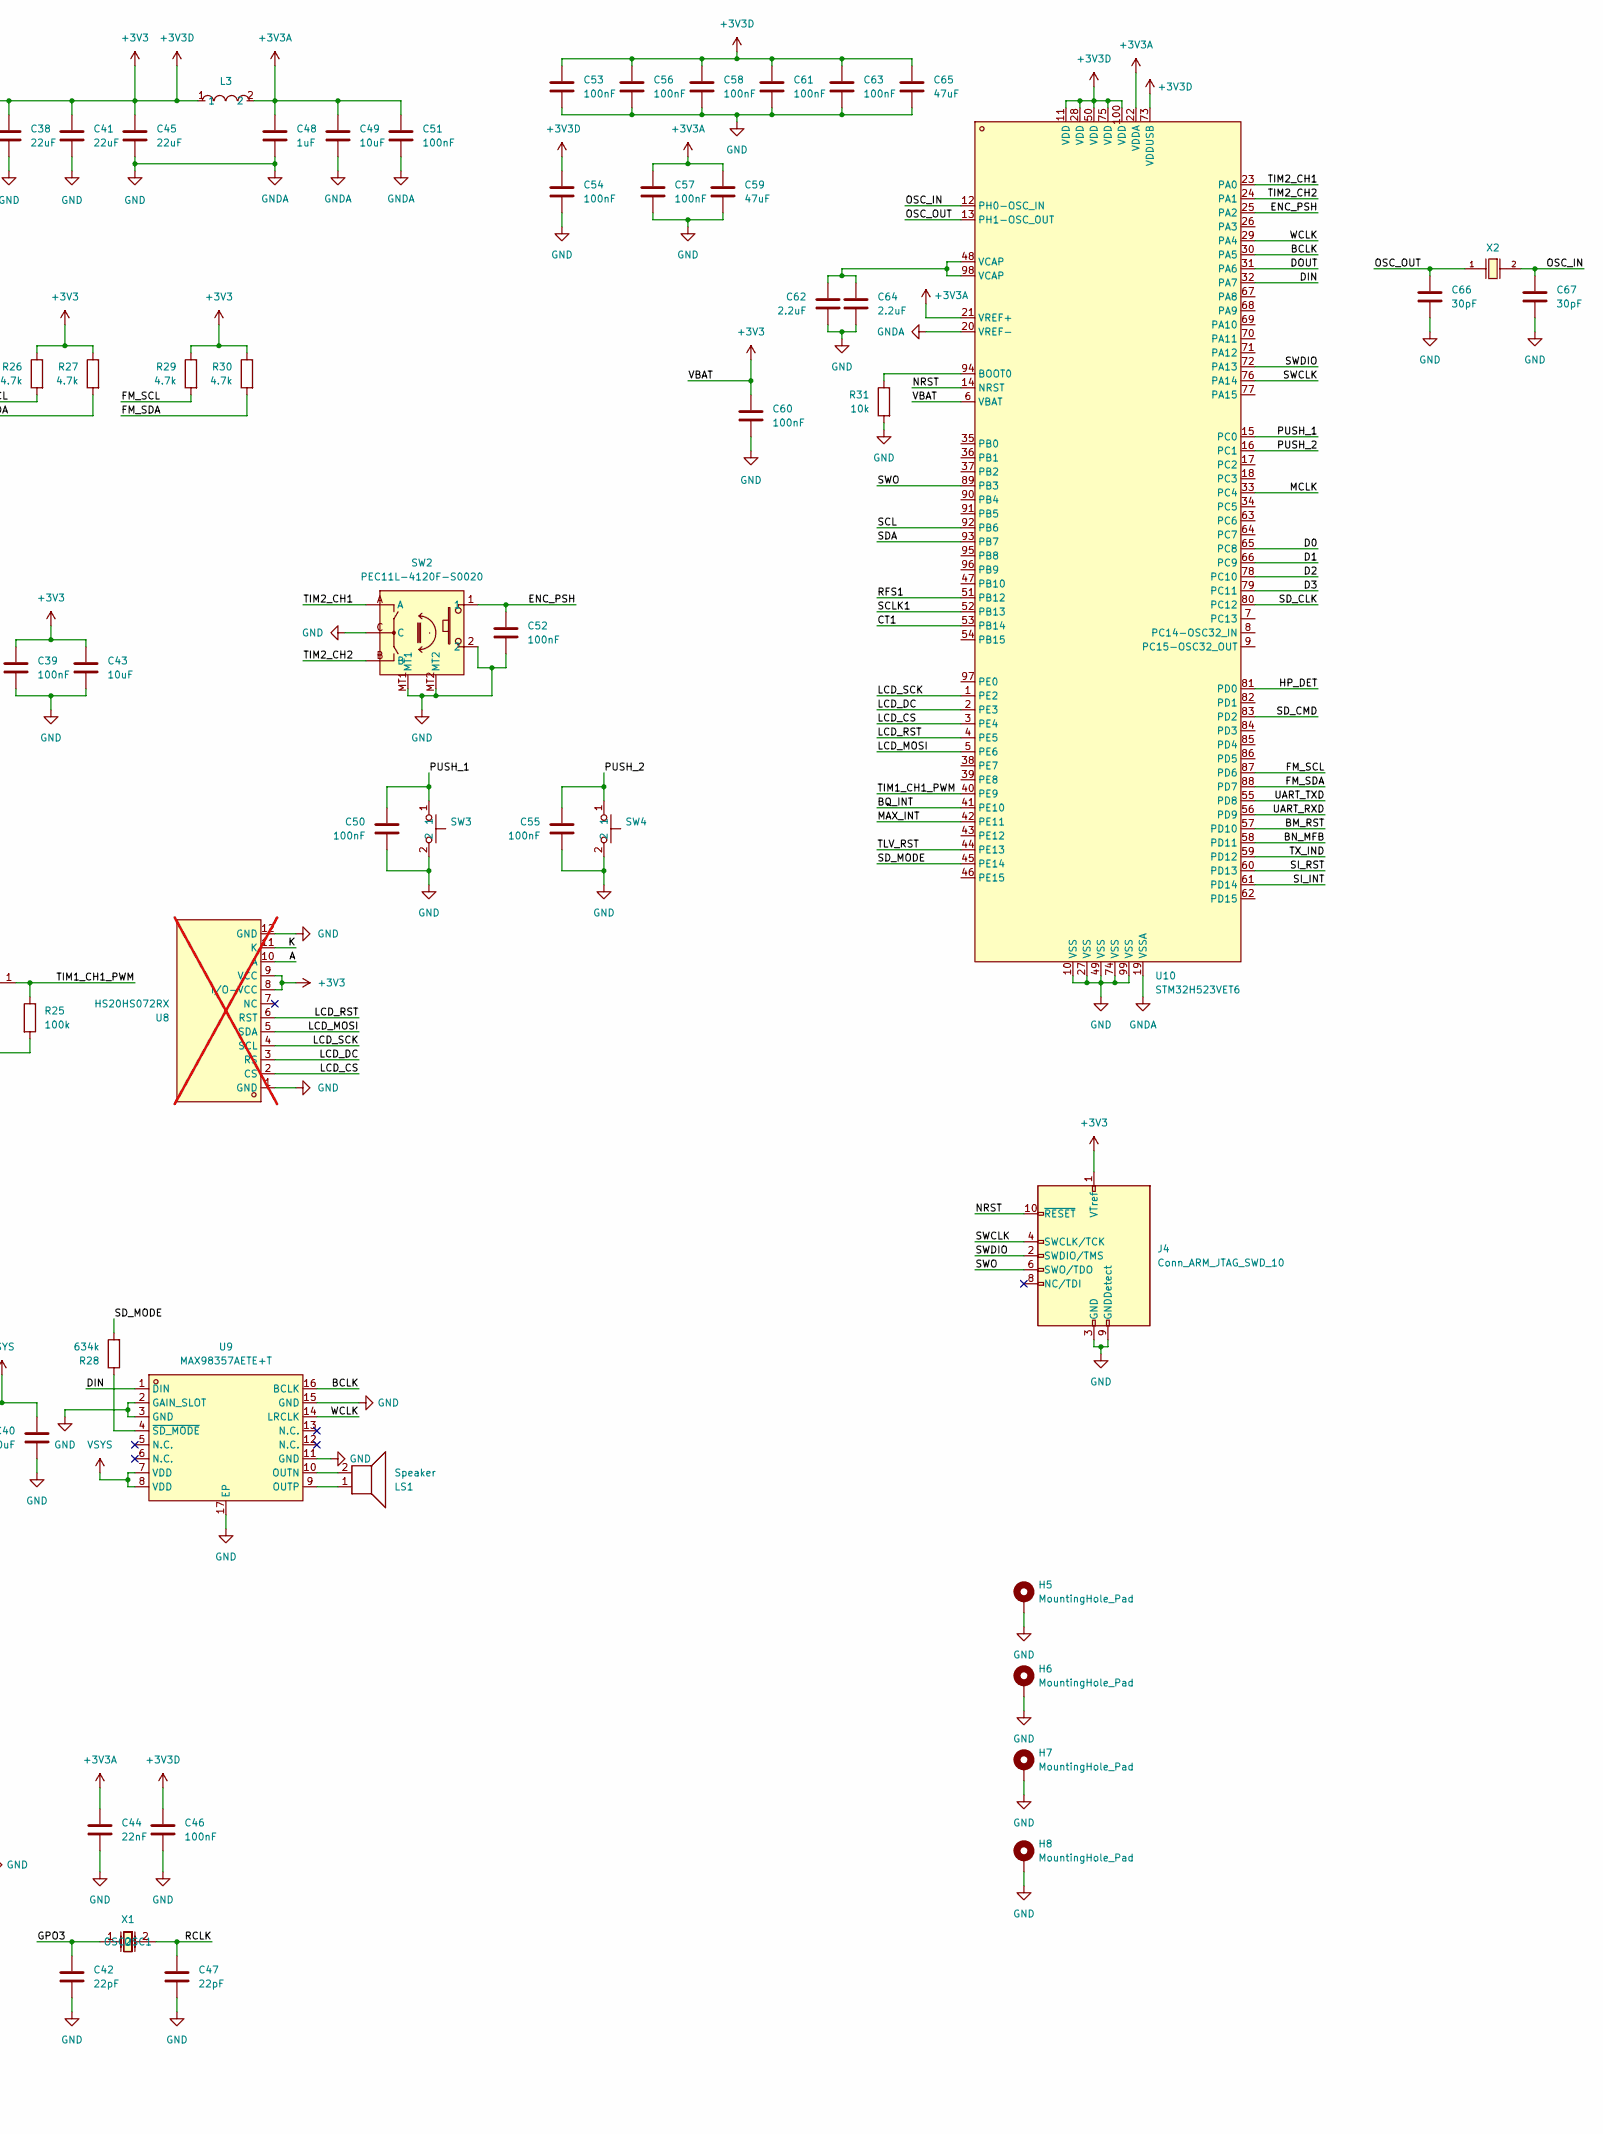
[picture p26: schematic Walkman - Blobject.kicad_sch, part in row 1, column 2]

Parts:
BT1: Battery_Cell; JST_PH_B2B-PH-K_1x02_P2.00mm_Vertical
C1, C10, C17, C22, C28, C29, C31, C32, C34, C48: 1uF; C_0603_1608Metric
C2: 4.7uF; C_0603_1608Metric
C3, C8, C9, C11, C12, C19, C24, C25, C27, C30, C33, C37, C39, C46, C50, C51, C52, C53, C54, C55, C56, C57, C58, C60, C61, C63, C68: 100nF; C_0603_1608Metric
C4, C13, C14, C15, C16, C21, C36, C40, C43, C49: 10uF; C_0603_1608Metric
C5, C6: 100uF; CP_Elec_5x5.4
C7: 47nF; C_0603_1608Metric
C18, C20: 470nF; C_0603_1608Metric
C35: 1nF; C_0201_0603Metric
C38, C41, C45: 22uF; C_0603_1608Metric
C42, C47: 22pF; C_0603_1608Metric
C44: 22nF; C_0603_1608Metric
C59, C65: 47uF; C_0603_1608Metric
C62, C64: 2.2uF; C_0603_1608Metric
C66, C67: 30pF; C_0603_1608Metric
D1: LED; LED_0603_1608Metric
D2: SMF5.0CA; D_SOD-123FL; Part SMF5.0CA; LCSC C19077498
D3: D_TVS; D_0201_0603Metric; LCSC C672369
F1: Polyfuse; Fuse_1206_3216Metric; LCSC C883127
FPC1: FPC05012-09200; FPC-SMD_FPC05012-09200; MPN FPC05012-09200; LCSC Part C479750
H5, H6, H7, H8: MountingHole_Pad; MountingHole_2.2mm_M2_Pad_Via
IC1: SI4705-D60-GM; SI4705D60GM; Manufacturer_Part_Number SI4705-D60-GM; Mouser Part Number N/A
J1: USB_C_Receptacle_USB2.0_16P; USB_C_Receptacle_HRO_TYPE-C-31-M-12; LCSC C2765186
J2: Micro_SD_Card; microSD_HC_Hirose_DM3AT-SF-PEJM5
J3: U.FL; IPEX-SMD_BWIPX-1-001E; LCSC C5137195
J4: Conn_ARM_JTAG_SWD_10; PinHeader_2x05_P1.27mm_Vertical
J6: AudioJack3_SwitchTR; Jack_3.5mm_CUI_SJ1-3525N_Horizontal
L1: 2.2uH; IND-SMD_L5.0-W5.0_SWPA5040S
L2: XFL4020-152MEC; IND-SMD_L4.0-W4.0-A; MPN XFL4020-152MEC; LCSC Part C3033018
L3: MPZ2012S601AT000; L0805; MPN MPZ2012S601AT000; LCSC Part C21519
LS1: Speaker; Molex_PicoBlade_53398-0271_1x02-1MP_P1.25mm_Vertical
Q1: AO3400A; SOT-23-3_L2.9-W1.3-P1.90-LS2.4-BR; MPN AO3400A; LCSC Part C20917
R1: 2.2k; R_0603_1608Metric
R2, R3, R4, R5, R8, R10, R11, R15, R17, R31, R32, R36: 10k; R_0603_1608Metric
R6, R7: 5k1; R_0603_1608Metric; LCSC C27834
R9: 260; R_0603_1608Metric
R12, R13: 0; R_0603_1608Metric
R14, R25, R34: 100k; R_0603_1608Metric
R16: 470k; R_0603_1608Metric
R18: 150k; R_0603_1608Metric
R19, R20, R21, R22, R24: 47k; R_0603_1608Metric; LCSC C17673
R23: 6.8; R_0603_1608Metric; LCSC C17673
R26, R27, R29, R30: 4.7k; R_0603_1608Metric
R28: 634k; R_0603_1608Metric
R35: 1k; R_0603_1608Metric; LCSC C17673
SW1: SW_Push; SW-SMD_L3.9-W3.0-P4.45
SW2: PEC11L-4120F-S0020; SW-TH_PEC11R-4XXXF-SXXXX; MPN PEC11L-4120F-S0020; LCSC Part C20882995
SW3, SW4: SW_PUSH_12x12x12mm_4Pin_SMD; MPN 12x12x12mm 4-pin tactile pushbutton
TP1, TP2, TP3, TP4, TP5: TestPoint; TestPoint_Pad_D1.0mm
U1: Microchip_BM83
U2: BQ25895RTWR; QFN-24_L4.0-W4.0-P0.50-TL-EP2.7; MPN BQ25895RTWR; LCSC Part C80200
U3: TLV320AIC3104IRHBR; HVQFN-32_L5.0-W5.0-P0.50-TL-EP; MPN TLV320AIC3104IRHBR; LCSC Part C181753
U4: USBLC6-2SC6; SOT-23-6
U5: MAX17048G+T10; TDFN-8_L2.0-W2.0-P0.50-BL-EP1.2; MPN MAX17048G+T10; LCSC Part C2682616
U6: AP2112K-1.8; SOT-23-5
U7: TPS63070RNMR; VQFN-15_L3.0-W2.5-P0.50-BL; MPN TPS63070RNMR; LCSC Part C109322
U8: HS20HS072RX; OLED-SMD_HS20HS072RX; MPN HS20HS072RX; LCSC Part C5329582; not fitted
U9: MAX98357AETE+T; TQFN-16_L3.0-W3.0-P0.50-BL-EP1.5; MPN MAX98357AETE+T; LCSC Part C910544
U10: STM32H523VET6; LQFP-100_L14.0-W14.0-P0.50-LS16.0-BL; MPN STM32H523VET6; LCSC Part C27338462
X1: ABS07-32.768KHZ-T; OSC-SMD_2P-L3.2-W1.5; MPN ABS07-32.768KHZ-T; LCSC Part C130253
X2: X50328MSB2GI; CRYSTAL-SMD_L5.0-W3.2; Frequency Tolerance ±10ppm; Part X50328MSB2GI; LCSC C115962

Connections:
+1V8: C3.2, C34.2, U3.32 (DVDD), U6.5 (VOUT)
+3V3: C9.1, C13.1, C19.1, C22.1, C25.1, C29.1, C31.2, C32.1, C33.1, C36.1, C38.1, C39.1, C41.1, C43.1, C45.1, C46.1, C53.1, C54.1, C56.1, C58.1, C60.1, C61.1, C63.1, C65.1, FPC1.8, FPC1.9, IC1.10 (VD), J2.4 (VDD), J4.1 (VTref), L3.1, R3.1, R4.1, R14.2, R16.1, R19.1, R20.1, R21.1, R22.1, R23.2, R24.1, R26.1, R27.1, R29.1, R30.1, R32.1, R34.1, U1.23 (BAT_IN), U3.7 (IOVDD), U3.18 (DRVDD), U3.24 (DRVDD), U6.1 (VIN), U6.3 (EN), U7.7 (Vout), U8.8 (I/O-VCC), U8.9 (VCC), U10.6 (VBAT), U10.11 (VDD), U10.28 (VDD), U10.50 (VDD), U10.73 (VDDUSB), U10.75 (VDD), U10.100 (VDD)
+3V3A: C8.1, C10.1, C12.1, C17.1, C21.1, C24.1, C28.1, C44.1, C48.1, C49.1, C51.1, C57.1, C59.1, IC1.11 (VA), L3.2, U3.25 (AVDD), U10.21 (VREF+), U10.22 (VDDA)
/A: FPC1.10, R23.1, U8.10 (A)
/BCLK: U3.2 (BCLK), U9.16 (BCLK), U10.30 (PA5)
/BM_RST: U1.43 (~RST), U10.57 (PD10)
/BN_MFB: U1.26 (PWR(MFB)), U10.58 (PD11)
/BQ_INT: R3.2, U2.7 (INT), U10.41 (PE10)
/Battery+: BT1.1 (+), C15.1, C27.2, U2.13 (BAT), U2.14 (BAT), U5.2 (CELL), U5.3 (VDD)
/CT1: U1.4 (DT1), U10.53 (PB14)
/D0: J2.7 (DAT0), R21.2, U10.65 (PC8)
/D1: J2.8 (DAT1), R19.2, U10.66 (PC9)
/D2: J2.1 (DAT2), R20.2, U10.78 (PC10)
/D3: J2.2 (DAT3/CD), R24.2, U10.79 (PC11)
/D+: J1.A6 (D+), J1.B6 (D+), U4.1 (I/O1)
/D-: J1.A7 (D-), J1.B7 (D-), U4.3 (I/O2)
/DIN: U3.4 (DIN), U9.1 (DIN), U10.32 (PA7)
/DOUT: U3.5 (DOUT), U10.31 (PA6)
/EN: R15.1, U7.1 (PS/SYNC), U7.14 (EN)
/ENC_PSH: C52.1, SW2.1, U10.25 (PA2)
/FB: R16.2, R18.1, U7.5 (FB)
/FM_ANT: C35.2, D3.2 (A2), J3.1 (In)
/FM_L: C20.1, IC1.14 (LOUT/[DFS])
/FM_R: C18.1, IC1.13 (ROUT/[DOUT])
/FM_SCL: IC1.7 (SCLK), R29.2, U10.87 (PD6)
/FM_SDA: IC1.8 (SDIO), R30.2, U10.88 (PD7)
/GPO3: C42.1, IC1.17 (GPO3/[DCLK]), X1.1 (OSC1)
/HPLOUT: C5.1, U3.19 (HPLOUT)
/HPROUT: C6.1, U3.23 (HPROUT)
/HP_DET: C68.1, R35.2, U10.81 (PD0)
/HP_TIP: J6.TN, R34.2, R35.1
/K: FPC1.11, Q1.3 (D), U8.11 (K)
/LCD_CS: FPC1.2, U8.2 (CS), U10.3 (PE4)
/LCD_DC: FPC1.3, U8.3 (RS), U10.2 (PE3)
/LCD_MOSI: FPC1.5, U8.5 (SDA), U10.5 (PE6)
/LCD_RST: FPC1.6, U8.6 (RST), U10.4 (PE5)
/LCD_SCK: FPC1.4, U8.4 (SCL), U10.1 (PE2)
/MAX_INT: R32.2, U5.5 (~ALRT), U10.42 (PE11)
/MCLK: U3.1 (MCLK), U10.33 (PC4)
/NRST: J4.10 (~RESET), U10.14 (NRST)
/OSC_IN: C67.1, U10.12 (PH0-OSC_IN), X2.2
/OSC_OUT: C66.1, U10.13 (PH1-OSC_OUT), X2.1
/PG: R14.1, U7.2 (PG)
/PMID: C4.1, U2.23 (PMID)
/PUSH_1: C50.1, SW3.1, U10.15 (PC0)
/PUSH_2: C55.1, SW4.1, U10.16 (PC1)
/P_D+: U2.2 (D+), U4.6 (I/O1)
/P_D-: U2.3 (D–), U4.4 (I/O2)
/QON: C11.1, SW1.2, TP4.1, U2.12 (QON)
/RCLK: C47.1, IC1.9 (RCLK), X1.2 (OSC2)
/REGN: C2.1, R11.1, U2.22 (REGN)
/RFS1: U1.2 (RFS1), U10.51 (PB12)
/SCL: R26.2, U2.5 (SCL), U3.8 (SCL), U5.7 (SCL), U10.92 (PB6)
/SCLK1: U1.3 (SCLK1), U10.52 (PB13)
/SDA: R27.2, U2.6 (SDA), U3.9 (SDA), U5.8 (SDA), U10.93 (PB7)
/SD_CLK: J2.5 (CLK), U10.80 (PC12)
/SD_CMD: J2.3 (CMD), R22.2, U10.83 (PD2)
/SD_MODE: R28.2, U10.45 (PE14)
/SI_INT: IC1.18 (GPO2/[~INT]), U10.61 (PD14)
/SI_RST: IC1.5 (~RST), R17.2, U10.60 (PD13)
/SWCLK: J4.4 (SWCLK/TCK), U10.76 (PA14)
/SWDIO: J4.2 (SWDIO/TMS), U10.72 (PA13)
/SWO: J4.6 (SWO/TDO), U10.89 (PB3)
/TIM1_CH1_PWM: Q1.1 (G), R25.1, U10.40 (PE9)
/TIM2_CH1: SW2.A, U10.23 (PA0)
/TIM2_CH2: SW2.B, U10.24 (PA1)
/TLV_RST: R2.2, U3.31 (~RESET), U10.44 (PE13)
/TX_IND: U1.49 (P0_0/UART_TX_IND), U10.59 (PD12)
/UART_RXD: R12.2, U10.56 (PD9)
/UART_TXD: R13.2, U10.55 (PD8)
/WCLK: U3.3 (WCLK), U9.14 (LRCLK), U10.29 (PA4)
GND: BT1.2 (-), C1.2, C2.2, C3.1, C4.2, C8.2, C9.2, C10.2, C11.2, C12.2, C13.2, C14.2, C15.2, C16.2, C17.2, C19.2, C21.2, C22.2, C24.2, C25.2, C27.1, C28.2, C29.2, C30.1, C31.1, C32.2, C33.2, C34.1, C36.2, C37.2, C38.2, C39.2, C40.2, C41.2, C42.2, C43.2, C44.2, C45.2, C46.2, C47.2, C48.2, C49.2, C50.2, C51.2, C52.2, C53.2, C54.2, C55.2, C56.2, C57.2, C58.2, C59.2, C60.2, C61.2, C62.2, C63.2, C64.2, C65.2, C66.2, C67.2, C68.2, D2.1, D3.1 (A1), FPC1.1, FPC1.12, FPC1.13, FPC1.14, H5.1, H6.1, H7.1, H8.1, IC1.3 (RFGND), IC1.6 (~SEN), IC1.12 (GND), IC1.21 (EP_GND), J1.A1 (GND), J1.A12 (GND), J1.B1 (GND), J1.B12 (GND), J1.S1 (SHIELD), J2.6 (VSS), J2.9 (SHIELD), J3.2 (Ext), J4.3 (GND), J4.5 (GND), J4.9 (GNDDetect), J6.S, Q1.2 (S), R2.1, R5.1, R6.2, R7.1, R8.1, R9.2, R10.2, R17.1, R18.2, R25.2, R31.2, R36.2, SW1.1, SW2.2, SW2.C, SW2.MT1, SW2.MT2, SW3.2, SW4.2, U1.16 (GND), U1.50 (GND), U1.56 (GND), U1.57 (GND), U2.17 (PGND), U2.18 (PGND), U2.25 (PAD), U3.6 (DVSS), U3.17 (AVSS1), U3.21 (DRVSS), U3.26 (AVSS2), U3.33 (EP), U4.2 (GND), U5.1 (CTG), U5.4 (GND), U5.6 (QSTRT), U5.9 (EP), U6.2 (GND), U7.4 (GND), U7.6 (FB2), U7.10 (PGND), U7.15 (Vsel), U8.1 (GND), U8.12 (GND), U9.2 (GAIN_SLOT), U9.3 (GND), U9.11 (GND), U9.15 (GND), U9.17 (EP), U10.10 (VSS), U10.19 (VSSA), U10.20 (VREF-), U10.27 (VSS), U10.49 (VSS), U10.74 (VSS), U10.99 (VSS)
unnamed: C5.2, J6.T, R36.1
unnamed: C6.2, J6.R
unnamed: C7.2, L1.1, U2.19 (SW), U2.20 (SW)
unnamed: C62.1, C64.1, U10.48 (VCAP), U10.98 (VCAP)
unnamed: D1.2 (A), R1.2
unnamed: D1.1 (K), U2.4 (STAT)
unnamed: F1.1, J1.A4 (VBUS), J1.A9 (VBUS), J1.B4 (VBUS), J1.B9 (VBUS)
unnamed: C35.1, IC1.2 (FMI)
unnamed: J1.A5 (CC1), R6.1
unnamed: J1.B5 (CC2), R7.2
unnamed: TP3.1, U1.22 (ADAP_IN)
unnamed: TP2.1, U1.36 (DM)
unnamed: TP1.1, U1.37 (DP)
unnamed: TP5.1, U1.31 (P3_4/UART_RTS)
unnamed: R12.1, U1.30 (P8_5/UART_TXD)
unnamed: R13.1, U1.29 (P8_6/UART_RXD)
unnamed: C7.1, U2.21 (BTST)
unnamed: R8.2, U2.9 (CE)
unnamed: R4.2, U2.24 (DSEL)
unnamed: R9.1, U2.10 (ILIM)
unnamed: R5.2, U2.8 (OTG)
unnamed: R10.1, R11.2, U2.11 (TS)
unnamed: C20.2, U3.14 (MIC2L/LINE2L/MICDET)
unnamed: C18.2, U3.16 (MIC2R/LINE2R)
unnamed: L2.1, U7.11 (L1)
unnamed: L2.2, U7.9 (L2)
unnamed: C30.2, U7.3 (Vaux)
unnamed: LS1.2, U9.10 (OUTN)
unnamed: LS1.1, U9.9 (OUTP)
unnamed: R28.1, U9.4 (~SD_MODE)
unnamed: R31.1, U10.94 (BOOT0)
VBUS: C1.1, D2.2, F1.2, U2.1 (VBUS), U4.5 (VBUS)
VSYS: C14.1, C16.1, C37.1, C40.1, L1.2, R1.1, R15.2, U2.15 (SYS), U2.16 (SYS), U7.12 (Vin), U9.7 (VDD), U9.8 (VDD)

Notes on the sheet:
Red LED

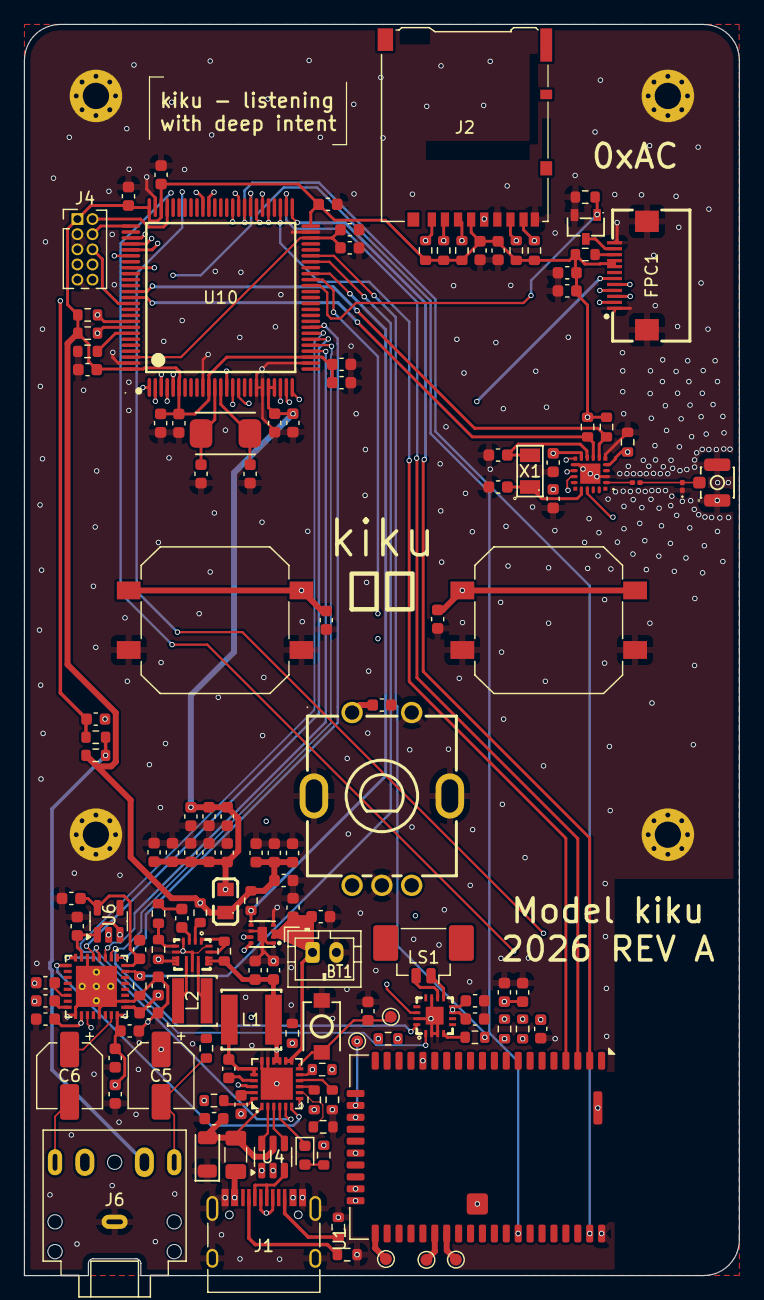
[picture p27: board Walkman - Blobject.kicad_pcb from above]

Board: 4 copper layers, 60.0 x 105.0 mm, 142 parts (0 on the bottom side), 105 nets.

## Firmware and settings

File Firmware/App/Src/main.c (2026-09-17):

#include "app.h"
#include "audio_stream.h"
#include "main.h"
#include "platform.h"
#include "ui_renderer.h"

#include "FreeRTOS.h"
#include "task.h"

static platform_devices_t s_platform;
static kiku_app_t s_app;

/* SWD bench mailbox: write a frequency in 10 kHz units to request FM from
 * the application task, where HAL delays and audio routing are safe. Zero
 * is idle. Normal boot behaviour is unchanged; result is a dev_status_t. */
volatile uint32_t g_bench_fm_request_10khz;
volatile uint32_t g_bench_volume_percent = 25U;
volatile int32_t g_bench_fm_result = DEV_ENOTREADY;
/* -1 seeks down, +1 seeks up, 0 idle. */
volatile int32_t g_bench_fm_seek_request;
volatile int32_t g_bench_fm_seek_result = DEV_ENOTREADY;
volatile uint32_t g_bench_power_toggle_request;

/* GCC -fstack-usage shows the deepest MP3 decode path at roughly 21.5 KiB
 * (minimp3 frame decoder + local playback frame). 8K Cortex-M33 stack words
 * gives a 32 KiB task stack with useful margin for HAL/FatFs call depth. */
#define APP_TASK_STACK_WORDS 8192U
#define LOCAL_PREFILL_FRAMES 6144U /* 128 ms at 48 kHz */

static uint16_t animation_ease(uint16_t progress)
{
    uint64_t p = progress > 1000U ? 1000U : progress;
    uint64_t p2 = p * p;
    uint64_t p3 = p2 * p;
    uint64_t eased = (p3 * (10000000ULL + p * (6ULL * p - 15000ULL)) +
                       500000000000ULL) / 1000000000000ULL;
    if (eased > 1000ULL) eased = 1000ULL;
    return (uint16_t)eased;
}

static uint16_t transition_backlight_level(const kiku_app_t *app)
{
    uint32_t full = (uint32_t)app->ui.brightness_percent * 100U;
    uint32_t visible = 1000U;
    if (app->ui.screen == UI_SCREEN_BOOT || app->ui.screen == UI_SCREEN_POWERING_ON) {
        /* Start with a deliberate low glow after the first animation frame has
         * reached GRAM. A completely black 0% first half looked like there was
         * no boot animation on the physical unit, especially at low brightness. */
        uint32_t eased = animation_ease(app->ui.animation_progress);
        visible = 160U + ((840U * eased + 500U) / 1000U);
    } else if (app->ui.screen == UI_SCREEN_POWERING_OFF) {
        /* Fade for the whole transition rather than cramming the luminance
         * change into its second half. With 0.01%-resolution PWM this removes
         * the visible staircase near black. */
        visible = 1000U - animation_ease(app->ui.animation_progress);
    }
    return (uint16_t)((full * visible + 500U) / 1000U);
}

static void prefill_local_audio(void)
{
    if (!s_app.initialised || s_app.audio.source != AUDIO_SOURCE_LOCAL ||
        !s_app.local.playing || s_app.local.file == NULL) return;

    /* A full 320x240 software-rendered SPI frame can occupy the foreground
     * task for tens of milliseconds. Keep ~128 ms queued before rendering so
     * the circular I2S DMA never depends on foreground/UI latency. */
    for (unsigned guard = 0U; guard < 16U &&
         audio_stream_queued_frames() < LOCAL_PREFILL_FRAMES; ++guard) {
        dev_status_t st = local_playback_process(&s_app.local);
        if (st == DEV_EBUSY) break;
        if (st != DEV_OK || s_app.local.eof) break;
    }
}

static void app_task(void *argument)
{
    (void)argument;
    dev_status_t st = platform_devices_init(&s_platform);
    if (st == DEV_OK) st = kiku_app_init(&s_app, &s_platform.deps);
    if (st == DEV_OK) s_app.ui.storage_mounted = storage_is_mounted(&s_platform.storage);

    uint32_t last_render = 0U;
    bool was_soft_powered_off = false;
    if (st == DEV_OK && s_app.ui.screen == UI_SCREEN_BOOT) {
        /* Prime the panel synchronously and start the boot timer only after the
         * first visible animation frame is physically present. This makes cold
         * boot deterministic instead of allowing init/display latency to eat
         * the beginning of the animation. */
        s_app.ui.animation_progress = 0U;
        ui_renderer_invalidate();
        (void)ui_renderer_draw(&s_platform.display, &s_app.ui);
        s_app.transition_started_ms = HAL_GetTick();
        last_render = s_app.transition_started_ms;
        platform_set_backlight_level(transition_backlight_level(&s_app));
    }
    for (;;) {
        if (st == DEV_OK) {
            if (g_bench_power_toggle_request != 0U) {
                g_bench_power_toggle_request = 0U;
                kiku_app_toggle_soft_power(&s_app);
            }
            uint32_t requested_fm = g_bench_fm_request_10khz;
            if (requested_fm != 0U) {
                g_bench_fm_request_10khz = 0U;
                if (requested_fm < APP_FM_MIN_10KHZ || requested_fm > APP_FM_MAX_10KHZ) {
                    g_bench_fm_result = DEV_EINVAL;
                } else {
                    uint8_t volume = (uint8_t)(g_bench_volume_percent > 100U ?
                                               100U : g_bench_volume_percent);
                    s_app.settings.value.volume_percent = volume;
                    s_app.ui.volume_percent = volume;
                    g_bench_fm_result = audio_router_set_volume(&s_app.audio, volume);
                    if (g_bench_fm_result == DEV_OK) {
                        g_bench_fm_result = kiku_app_tune_fm(&s_app, (uint16_t)requested_fm);
                    }
                }
            }
            int32_t requested_seek = g_bench_fm_seek_request;
            if (requested_seek != 0) {
                g_bench_fm_seek_request = 0;
                if (requested_seek != -1 && requested_seek != 1) {
                    g_bench_fm_seek_result = DEV_EINVAL;
                } else {
                    g_bench_fm_seek_result = kiku_app_seek_fm(&s_app, requested_seek > 0);
                }
            }
            int16_t encoder = platform_encoder_delta();
            if (encoder != 0) kiku_app_encoder_delta(&s_app, encoder);
            platform_poll_bm83(&s_app);
            (void)kiku_app_tick(&s_app);
            if (was_soft_powered_off && !s_app.soft_powered_off) {
                /* The LCD controller may retain GRAM across SLPIN/SLPOUT, but
                 * do not depend on that for a product transition. Force the
                 * first wake frame to be sent before the backlight is raised. */
                ui_renderer_invalidate();
                if (s_app.ui.screen == UI_SCREEN_POWERING_ON) {
                    s_app.ui.animation_progress = 0U;
                    (void)ui_renderer_draw(&s_platform.display, &s_app.ui);
                    s_app.transition_started_ms = HAL_GetTick();
                    last_render = s_app.transition_started_ms;
                    platform_set_backlight_level(transition_backlight_level(&s_app));
                } else {
                    last_render = 0U;
                }
            }
            if (s_app.soft_powered_off) {
                platform_set_backlight(0U);
                platform_watchdog_refresh();
                was_soft_powered_off = true;
                vTaskDelay(pdMS_TO_TICKS(20U));
                continue;
            }
            platform_service_stream_audio(&s_app);
            uint32_t now = HAL_GetTick();
            bool animating = s_app.ui.screen == UI_SCREEN_BOOT ||
                             s_app.ui.screen == UI_SCREEN_POWERING_OFF ||
                             s_app.ui.screen == UI_SCREEN_POWERING_ON;
            uint32_t render_period = animating ? APP_ANIMATION_FRAME_MS :
                                     (s_app.settings.value.power_save_enabled != 0U ?
                                      APP_POWER_SAVE_RENDER_PERIOD_MS : APP_NORMAL_RENDER_PERIOD_MS);
            if ((uint32_t)(now - last_render) >= render_period) {
                prefill_local_audio();
                (void)ui_renderer_draw(&s_platform.display, &s_app.ui);
                /* Rendering is the longest normal foreground operation. Drain
                 * BM83 immediately afterwards instead of adding another task
                 * period of Command/Event_ACK latency. */
                platform_poll_bm83(&s_app);
                last_render = now;
            }
            /* Update luminance only after any due frame has reached GRAM. This
             * prevents wake-up from exposing a stale pre-sleep frame for even a
             * single visible refresh. */
            platform_set_backlight_level(transition_backlight_level(&s_app));
            was_soft_powered_off = false;
            platform_watchdog_refresh();
        }
        /* On a fatal platform/application initialisation error deliberately do
         * not refresh IWDG. The board will reset instead of hanging forever in
         * an unusable state while appearing healthy to the watchdog. */
        vTaskDelay(pdMS_TO_TICKS(10U));
    }
}

int main(void)
{
    Board_Init();
    if (xTaskCreate(app_task, "App", APP_TASK_STACK_WORDS, NULL,
                    tskIDLE_PRIORITY + 3U, NULL) != pdPASS) {
        Error_Handler();
    }
    vTaskStartScheduler();
    Error_Handler();
    return 0;
}

void vApplicationStackOverflowHook(TaskHandle_t task, char *task_name)
{
    (void)task; (void)task_name;
    taskDISABLE_INTERRUPTS();
    Error_Handler();
}

void vApplicationMallocFailedHook(void)
{
    taskDISABLE_INTERRUPTS();
    Error_Handler();
}

void vApplicationIdleHook(void)
{
    /* The application task deliberately sleeps between 10 ms service passes.
     * Without an idle hook FreeRTOS spins at 160 MHz for all of that time,
     * which dominates both awake-idle and soft-off battery current. Keep the
     * normal clocks/peripherals running, but halt the Cortex-M33 core until the
     * next SysTick/HAL/peripheral interrupt. Audio DMA, UART, timers and the
     * watchdog therefore keep their existing behaviour while CPU dynamic power
     * drops whenever there is no useful work to do. */
    __DSB();
    __WFI();
    __ISB();
}

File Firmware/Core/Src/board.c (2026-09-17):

#include "main.h"

I2C_HandleTypeDef hi2c1;
I2C_HandleTypeDef hi2c3;
SPI_HandleTypeDef hspi4;
I2S_HandleTypeDef hi2s1;
I2S_HandleTypeDef hi2s2;
UART_HandleTypeDef huart3;
SD_HandleTypeDef hsd1;
TIM_HandleTypeDef htim1;
TIM_HandleTypeDef htim2;
IWDG_HandleTypeDef hiwdg;

DMA_HandleTypeDef hdma_spi1_rx;
DMA_HandleTypeDef hdma_spi1_tx;
DMA_HandleTypeDef hdma_spi2_rx;
DMA_HandleTypeDef hdma_spi4_tx;
DMA_HandleTypeDef hdma_usart3_rx;
DMA_HandleTypeDef hdma_usart3_tx;

/* HSI64 kernel, approximately 100 kHz Standard-mode I2C.  The board has
 * external 4.7 kOhm pull-ups on both I2C buses. */
#define BOARD_I2C_TIMING_64MHZ_100KHZ  0x30424757UL

static void Board_DMAChannelInit(DMA_HandleTypeDef *hdma,
                                 DMA_Channel_TypeDef *instance,
                                 uint32_t request,
                                 uint32_t direction,
                                 uint32_t src_inc,
                                 uint32_t dest_inc,
                                 uint32_t src_width,
                                 uint32_t dest_width,
                                 uint32_t priority)
{
  hdma->Instance = instance;
  hdma->Init.Request = request;
  hdma->Init.BlkHWRequest = DMA_BREQ_SINGLE_BURST;
  hdma->Init.Direction = direction;
  hdma->Init.SrcInc = src_inc;
  hdma->Init.DestInc = dest_inc;
  hdma->Init.SrcDataWidth = src_width;
  hdma->Init.DestDataWidth = dest_width;
  hdma->Init.Priority = priority;
  hdma->Init.SrcBurstLength = 1U;
  hdma->Init.DestBurstLength = 1U;
  hdma->Init.TransferAllocatedPort = DMA_SRC_ALLOCATED_PORT0 | DMA_DEST_ALLOCATED_PORT0;
  hdma->Init.TransferEventMode = DMA_TCEM_BLOCK_TRANSFER;
  hdma->Init.Mode = DMA_NORMAL;

  if (HAL_DMA_Init(hdma) != HAL_OK)
  {
    Error_Handler();
  }

  if (HAL_DMA_ConfigChannelAttributes(hdma, DMA_CHANNEL_NPRIV) != HAL_OK)
  {
    Error_Handler();
  }
}

void SystemClock_Config(void)
{
  RCC_OscInitTypeDef osc = {0};
  RCC_ClkInitTypeDef clk = {0};

  if (HAL_PWREx_ControlVoltageScaling(PWR_REGULATOR_VOLTAGE_SCALE0) != HAL_OK)
  {
    Error_Handler();
  }

  /* 8 MHz HSE / 8 = 1 MHz, x320 = 320 MHz VCO, /2 = 160 MHz SYSCLK.
   * LSI is enabled here because IWDG starts from LSI. */
  osc.OscillatorType = RCC_OSCILLATORTYPE_HSE | RCC_OSCILLATORTYPE_HSI |
                       RCC_OSCILLATORTYPE_LSI;
  osc.HSEState = RCC_HSE_ON;
  osc.HSIState = RCC_HSI_ON;
  osc.HSIDiv = RCC_HSI_DIV1;
  osc.HSICalibrationValue = RCC_HSICALIBRATION_DEFAULT;
  osc.LSIState = RCC_LSI_ON;
  osc.PLL.PLLState = RCC_PLL_ON;
  osc.PLL.PLLSource = RCC_PLLSOURCE_HSE;
  osc.PLL.PLLM = 8U;
  osc.PLL.PLLN = 320U;
  osc.PLL.PLLP = 2U;
  osc.PLL.PLLQ = 8U; /* PLL1Q = 40 MHz for SDMMC1. */
  osc.PLL.PLLR = 8U;
  osc.PLL.PLLRGE = RCC_PLL1_VCIRANGE_0;
  osc.PLL.PLLVCOSEL = RCC_PLL1_VCORANGE_WIDE;
  osc.PLL.PLLFRACN = 0U;

  if (HAL_RCC_OscConfig(&osc) != HAL_OK)
  {
    Error_Handler();
  }

  clk.ClockType = RCC_CLOCKTYPE_SYSCLK | RCC_CLOCKTYPE_HCLK |
                  RCC_CLOCKTYPE_PCLK1 | RCC_CLOCKTYPE_PCLK2 |
                  RCC_CLOCKTYPE_PCLK3;
  clk.SYSCLKSource = RCC_SYSCLKSOURCE_PLLCLK;
  clk.AHBCLKDivider = RCC_SYSCLK_DIV1;
  clk.APB1CLKDivider = RCC_HCLK_DIV1;
  clk.APB2CLKDivider = RCC_HCLK_DIV1;
  clk.APB3CLKDivider = RCC_HCLK_DIV1;

  if (HAL_RCC_ClockConfig(&clk, FLASH_LATENCY_5) != HAL_OK)
  {
    Error_Handler();
  }
}

void Board_PeripheralClock_Config(void)
{
  RCC_PeriphCLKInitTypeDef periph = {0};

  periph.PeriphClockSelection = RCC_PERIPHCLK_I2C1 | RCC_PERIPHCLK_I2C3 |
                                RCC_PERIPHCLK_SPI1 | RCC_PERIPHCLK_SPI2 |
                                RCC_PERIPHCLK_SPI4 | RCC_PERIPHCLK_USART3 |
                                RCC_PERIPHCLK_SDMMC1;

  /* Dedicated low-jitter audio kernel.  With the verified 8 MHz HSE:
   * 8 MHz / 8 * (393 + 1769/8192) / 8 = 49.1519928 MHz (~-0.15 ppm).
   * HAL I2S then derives the requested 48 kHz audio clocks from PLL2P. */
  periph.PLL2.PLL2Source = RCC_PLL2_SOURCE_HSE;
  periph.PLL2.PLL2M = 8U;
  periph.PLL2.PLL2N = 393U;
  periph.PLL2.PLL2P = 8U;
  periph.PLL2.PLL2Q = 8U;
  periph.PLL2.PLL2R = 8U;
  periph.PLL2.PLL2RGE = RCC_PLL2_VCIRANGE_0;
  periph.PLL2.PLL2VCOSEL = RCC_PLL2_VCORANGE_WIDE;
  periph.PLL2.PLL2FRACN = 1769U;
  periph.PLL2.PLL2ClockOut = RCC_PLL2_DIVP;

  periph.I2c1ClockSelection = RCC_I2C1CLKSOURCE_HSI;
  periph.I2c3ClockSelection = RCC_I2C3CLKSOURCE_HSI;
  periph.Spi1ClockSelection = RCC_SPI1CLKSOURCE_PLL2P;
  periph.Spi2ClockSelection = RCC_SPI2CLKSOURCE_PLL2P;
  periph.Spi4ClockSelection = RCC_SPI4CLKSOURCE_PCLK2;
  periph.Usart3ClockSelection = RCC_USART3CLKSOURCE_PCLK1;
  periph.Sdmmc1ClockSelection = RCC_SDMMC1CLKSOURCE_PLL1Q;

  if (HAL_RCCEx_PeriphCLKConfig(&periph) != HAL_OK)
  {
    Error_Handler();
  }
}
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

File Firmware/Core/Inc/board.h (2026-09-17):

#ifndef KIKU_BOARD_H
#define KIKU_BOARD_H

#include "stm32h5xx_hal.h"

#ifdef __cplusplus
extern "C" {
#endif

/* Verified MCU clock source. */
#define BOARD_HSE_HZ                    8000000UL
#define BOARD_SYSCLK_HZ               160000000UL
#define BOARD_AUDIO_SAMPLE_RATE_HZ        48000UL

/* LCD: HS20HS072RX/ST7789 through FPC1. */
#define LCD_SCK_Pin                    GPIO_PIN_2
#define LCD_SCK_GPIO_Port              GPIOE
#define LCD_DC_Pin                     GPIO_PIN_3
#define LCD_DC_GPIO_Port               GPIOE
#define LCD_CS_Pin                     GPIO_PIN_4
#define LCD_CS_GPIO_Port               GPIOE
#define LCD_RST_Pin                    GPIO_PIN_5
#define LCD_RST_GPIO_Port              GPIOE
#define LCD_MOSI_Pin                   GPIO_PIN_6
#define LCD_MOSI_GPIO_Port             GPIOE

/* User controls. PUSH_1 and HP_DET both occupy EXTI line 0, so these
 * application-facing inputs are intentionally polled rather than EXTI-driven. */
#define PUSH_1_Pin                     GPIO_PIN_0
#define PUSH_1_GPIO_Port               GPIOC
#define PUSH_2_Pin                     GPIO_PIN_1
#define PUSH_2_GPIO_Port               GPIOC
#define ENC_A_Pin                      GPIO_PIN_0
#define ENC_A_GPIO_Port                GPIOA
#define ENC_B_Pin                      GPIO_PIN_1
#define ENC_B_GPIO_Port                GPIOA
#define ENC_PUSH_Pin                   GPIO_PIN_2
#define ENC_PUSH_GPIO_Port             GPIOA
#define HP_DET_Pin                     GPIO_PIN_0
#define HP_DET_GPIO_Port               GPIOD

/* I2S1: MCU master to TLV320AIC3104 and MAX98357A, with codec return data. */
#define AUDIO_WCLK_Pin                 GPIO_PIN_4
#define AUDIO_WCLK_GPIO_Port           GPIOA
#define AUDIO_BCLK_Pin                 GPIO_PIN_5
#define AUDIO_BCLK_GPIO_Port           GPIOA
#define AUDIO_DOUT_Pin                 GPIO_PIN_6
#define AUDIO_DOUT_GPIO_Port           GPIOA
#define AUDIO_DIN_Pin                  GPIO_PIN_7
#define AUDIO_DIN_GPIO_Port            GPIOA
#define AUDIO_MCLK_Pin                 GPIO_PIN_4
#define AUDIO_MCLK_GPIO_Port           GPIOC

/* Backlight and audio control. */
#define LCD_BL_PWM_Pin                 GPIO_PIN_9
#define LCD_BL_PWM_GPIO_Port           GPIOE
#define BQ_INT_Pin                     GPIO_PIN_10
#define BQ_INT_GPIO_Port               GPIOE
#define MAX_INT_Pin                    GPIO_PIN_11
#define MAX_INT_GPIO_Port              GPIOE
#define TLV_RST_Pin                    GPIO_PIN_13
#define TLV_RST_GPIO_Port              GPIOE
#define AMP_SD_MODE_Pin                GPIO_PIN_14
#define AMP_SD_MODE_GPIO_Port          GPIOE

/* BM83 digital audio and host interface. KiCad net /CT1 is BM83 DT1. */
#define BM83_RFS_Pin                   GPIO_PIN_12
#define BM83_RFS_GPIO_Port             GPIOB
#define BM83_SCLK_Pin                  GPIO_PIN_13
#define BM83_SCLK_GPIO_Port            GPIOB
#define BM83_DT_Pin                    GPIO_PIN_14
#define BM83_DT_GPIO_Port              GPIOB
#define BM83_UART_TX_Pin               GPIO_PIN_8
#define BM83_UART_TX_GPIO_Port         GPIOD
#define BM83_UART_RX_Pin               GPIO_PIN_9
#define BM83_UART_RX_GPIO_Port         GPIOD
#define BM83_RST_Pin                   GPIO_PIN_10
#define BM83_RST_GPIO_Port             GPIOD
#define BM83_MFB_Pin                   GPIO_PIN_11
#define BM83_MFB_GPIO_Port             GPIOD
#define BM83_TX_IND_Pin                GPIO_PIN_12
#define BM83_TX_IND_GPIO_Port          GPIOD

/* SI4705 FM tuner. */
#define SI4705_RST_Pin                 GPIO_PIN_13
#define SI4705_RST_GPIO_Port           GPIOD
#define SI4705_INT_Pin                 GPIO_PIN_14
#define SI4705_INT_GPIO_Port           GPIOD
#define FM_SCL_Pin                     GPIO_PIN_6
#define FM_SCL_GPIO_Port               GPIOD
#define FM_SDA_Pin                     GPIO_PIN_7
#define FM_SDA_GPIO_Port               GPIOD

/* microSD, native 4-bit SDMMC1. */
#define SD_D0_Pin                      GPIO_PIN_8
#define SD_D0_GPIO_Port                GPIOC
#define SD_D1_Pin                      GPIO_PIN_9
#define SD_D1_GPIO_Port                GPIOC
#define SD_D2_Pin                      GPIO_PIN_10
#define SD_D2_GPIO_Port                GPIOC
#define SD_D3_Pin                      GPIO_PIN_11
#define SD_D3_GPIO_Port                GPIOC
#define SD_CLK_Pin                     GPIO_PIN_12
#define SD_CLK_GPIO_Port               GPIOC
#define SD_CMD_Pin                     GPIO_PIN_2
#define SD_CMD_GPIO_Port               GPIOD

/* Shared I2C1 bus: BQ25895 + TLV320AIC3104 + MAX17048. */
#define SYS_I2C_SCL_Pin                GPIO_PIN_6
#define SYS_I2C_SCL_GPIO_Port          GPIOB
#define SYS_I2C_SDA_Pin                GPIO_PIN_7
#define SYS_I2C_SDA_GPIO_Port          GPIOB
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
